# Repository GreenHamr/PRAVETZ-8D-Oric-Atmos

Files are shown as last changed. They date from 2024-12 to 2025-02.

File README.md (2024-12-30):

PRAVETZ-8D Plus Project

An 8-bit home computer using a home TV instead of a monitor. 
Programmatically incompatible with Pravets 82 family computers (due to the different architecture). 
An analogue of Oric Atmos. At first, it only works with a tape recorder (after 1990, floppy drives 
for it also appeared, united in one housing with the controller[3]. 
It has improved sound capabilities, through a Yamaha microcircuit. It is widely used for home use 
and for training The extremely attractive price of the model (about 10 times lower than Pravets 82) 
gives high hopes for this model and not a few students have taken their first steps on Pravets 8D.

That's what happened to me. My first personal computer was a Pravetz-8D (Oric Atmos).

About a year ago I remembered my old childhood friend and wondered if I could make one of these.
Of course, first I called my mother to ask her if my old computer was still lying in a basement in my old house. To my great surprise, I found out that she had put it in a briefcase along with a pack of floppy disks.
A little battered and missing a single key, but - WORKING.
Unfortunately, the floppy disk drive and the controller were not preserved.

<br>
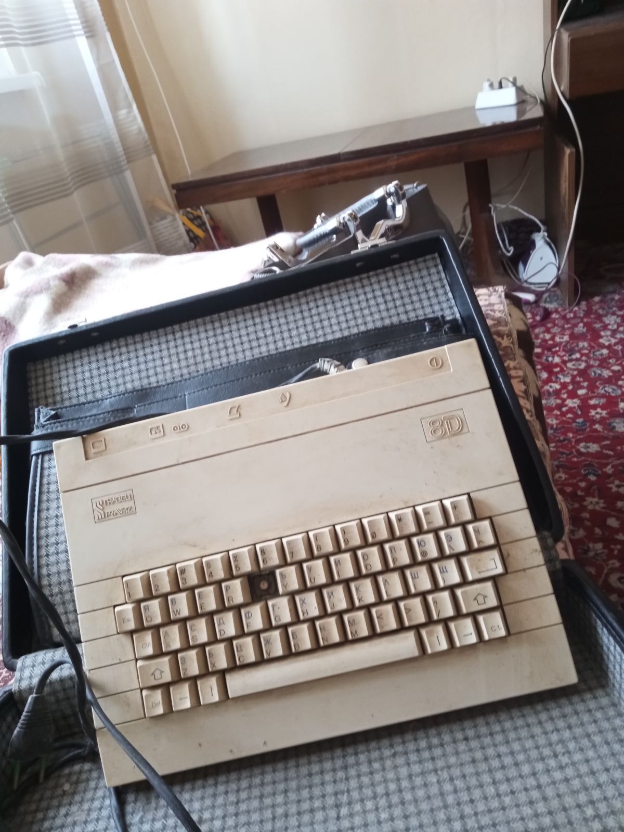
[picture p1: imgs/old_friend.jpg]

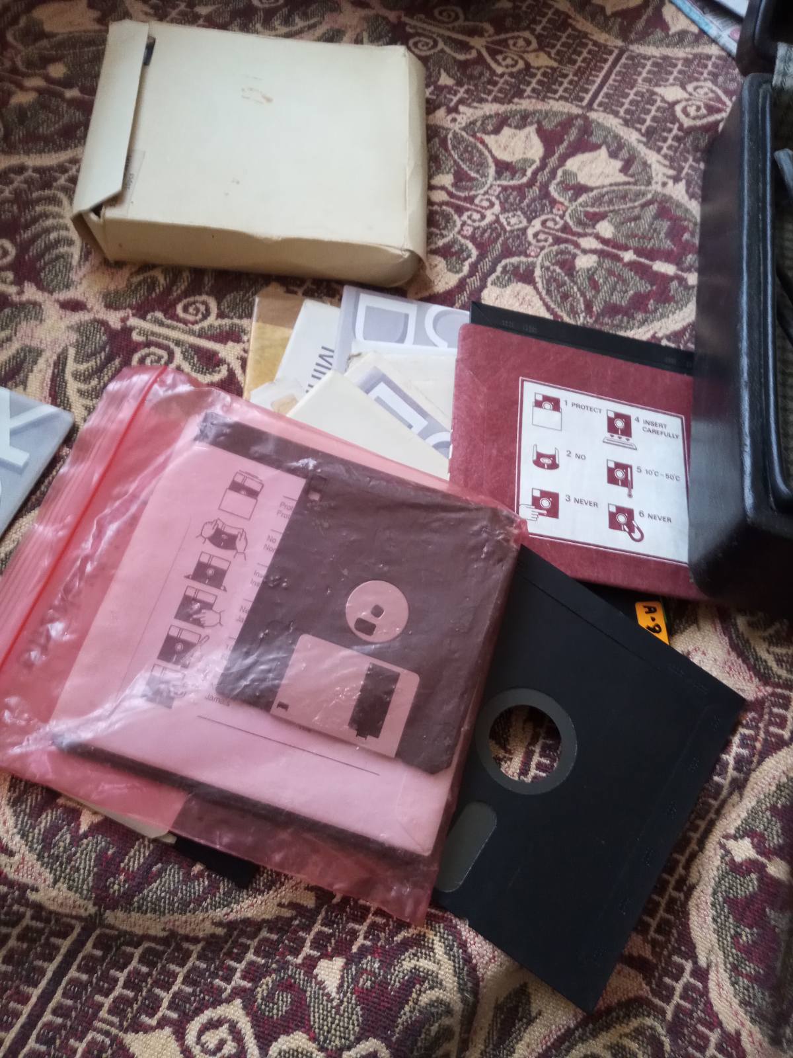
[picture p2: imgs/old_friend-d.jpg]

<br>

So, first I decided to make my own floppy disk controller. Some time ago I had bought one from Boyan Mitov - a very well made board.
I searched the internet but couldn't find a schematic. I bought a kit (a blank board plus PROMs) which I filled up and with a few extras I got it working. But the person I bought this board from said that there were only the gerbers and no schematic.

So I set out to develop such a controller myself.
And since we are already in the 21st century, I decided to use a Raspberry Pi (RP2040) microcontroller.

After several unsuccessful attempts and a lot of digging on the Internet , I got to assemble a floppy disk controller based on the RP2040 plus the schematic solution of the APPLE II for a floppy disk controller. (<a href = "https://en.wikipedia.org/wiki/Steve_Wozniak">WOZ</a> STATE MACHINE) - a very good solution.

During the development, I also had the idea of making a dynamic ROM. For this purpose, I used another RP 2040 which simulates the operation of a standard 27C128 ROM, but it has the ability to change four pages from one bank on the fly. I set eight banks that can be selected when the system is started.

I put all this together on one board. I also made a keyboard for it and the result is this:
<br>
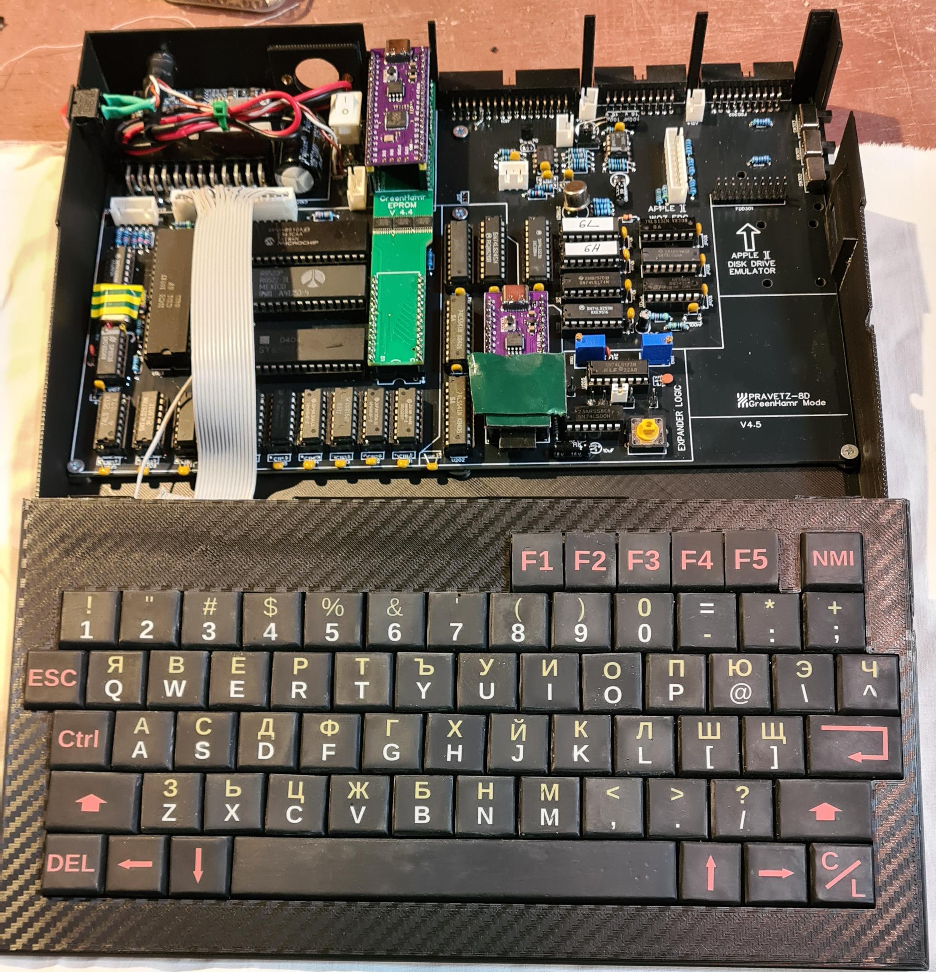
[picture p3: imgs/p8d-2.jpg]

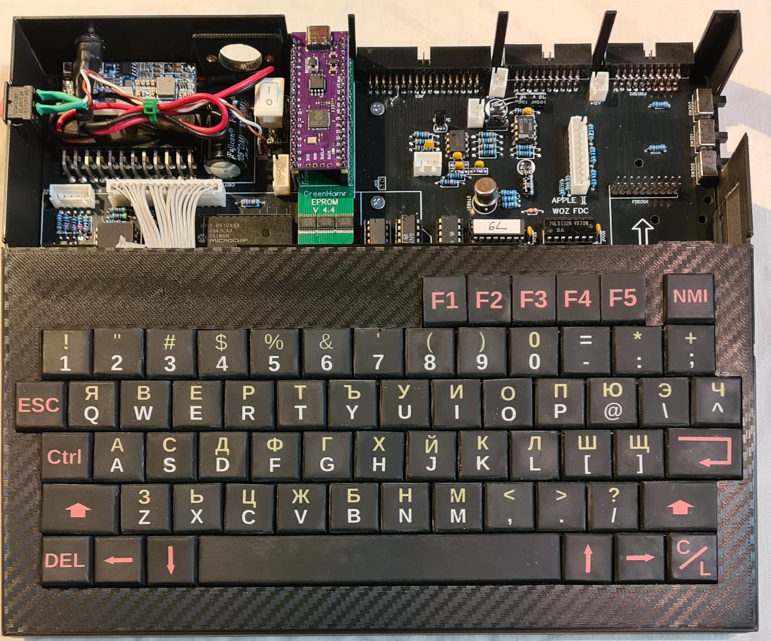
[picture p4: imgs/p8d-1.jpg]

<br>

I designed a box. It also underwent a lot of changes along with the changes in the board.

I encountered a problem with the monitor.
Pravets-8d (orits) has a monitor output (RGBS) which is however at 15kHz. I was unable to find such an LCD monitor. I found a converter board on the internet which works quite well, but it is very large and if I want to make this computer with nice shapes this board does not work for me.
So I set about making my own upscaler - another RP2040 which intercepts the video signal generated by the HCS10017 ULA and converts it to a standard LCD.

After I made the upscaler, I mounted everything in the top cover of the machine.

<br>
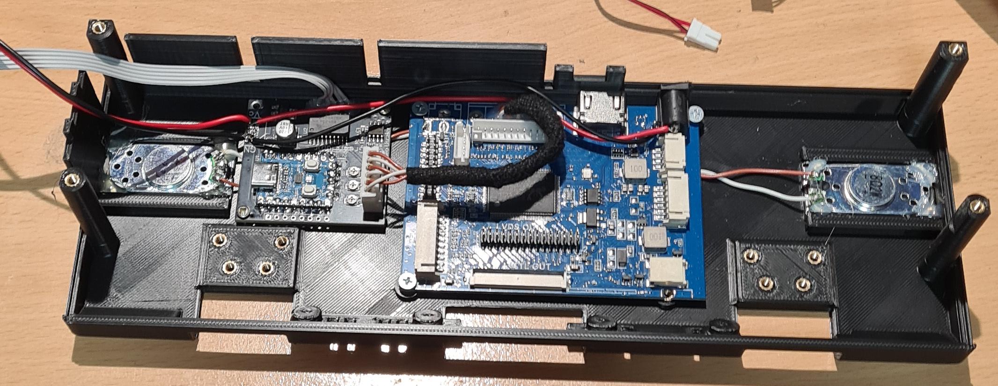
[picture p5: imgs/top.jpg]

<br>

And fully wired : 

<br>
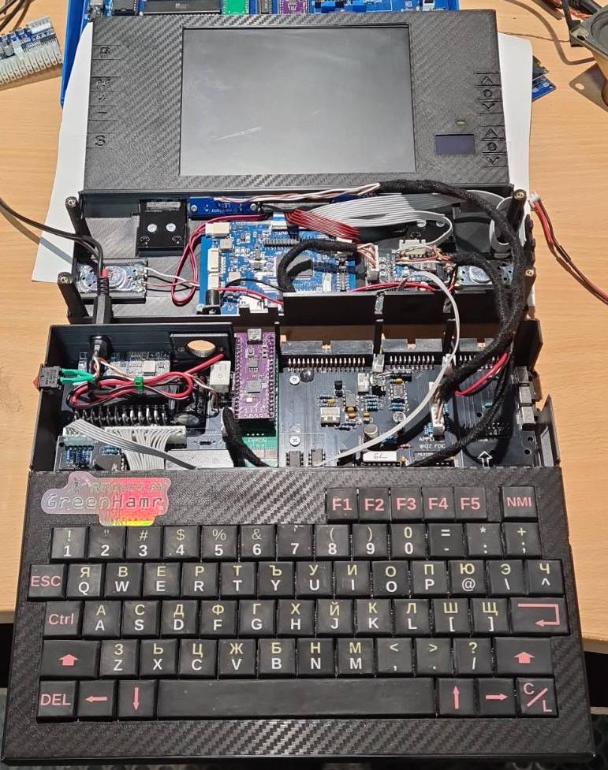
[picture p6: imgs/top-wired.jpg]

<br>

here is a back of dosplay : 

<br>
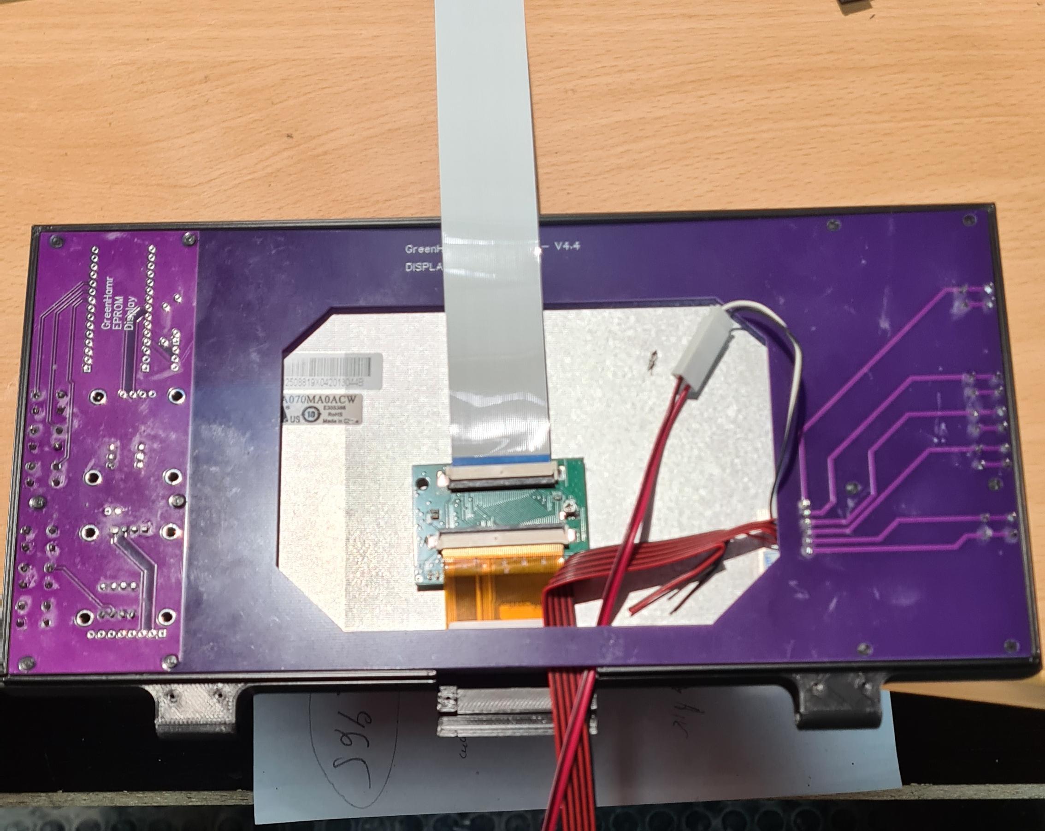
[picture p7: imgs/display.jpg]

<br>

So,
After I did all the wiring, it was finally time to close the whole computer and test it. Everything is OK.

<table border=0>
<tr>
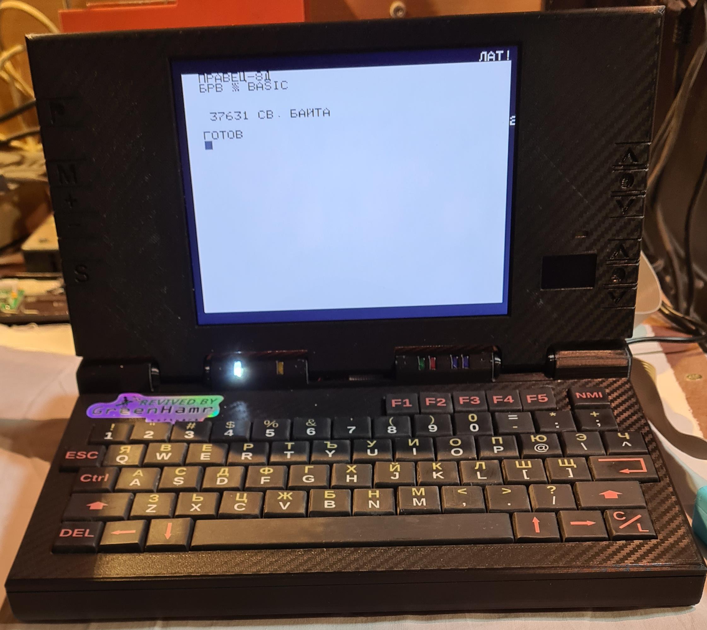
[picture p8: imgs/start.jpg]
<td></td>
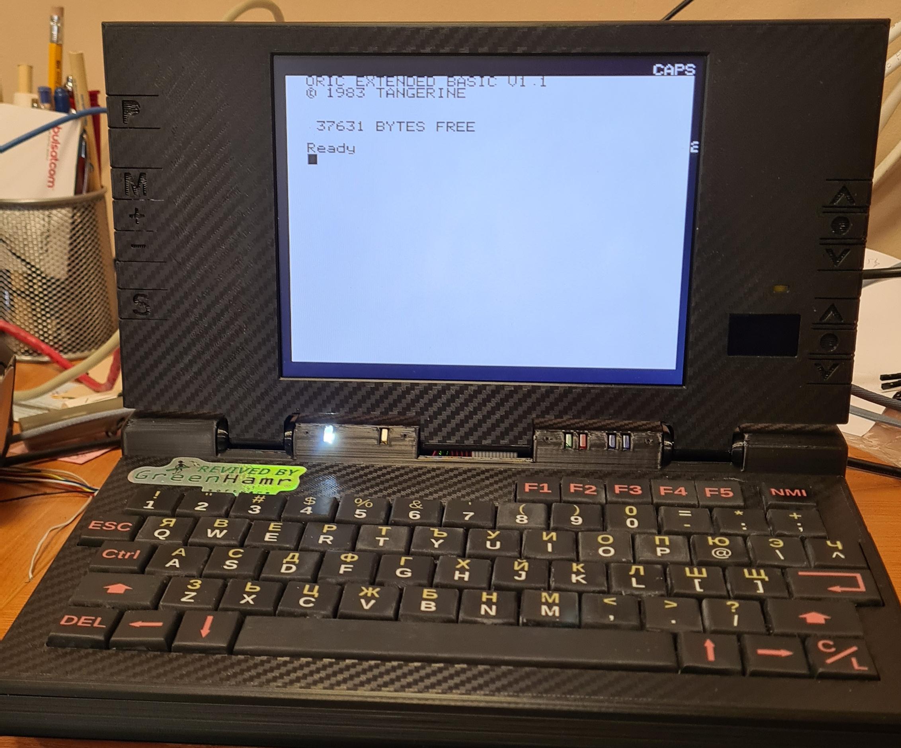
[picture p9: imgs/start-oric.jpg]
<td></td>
</tr>
<tr>
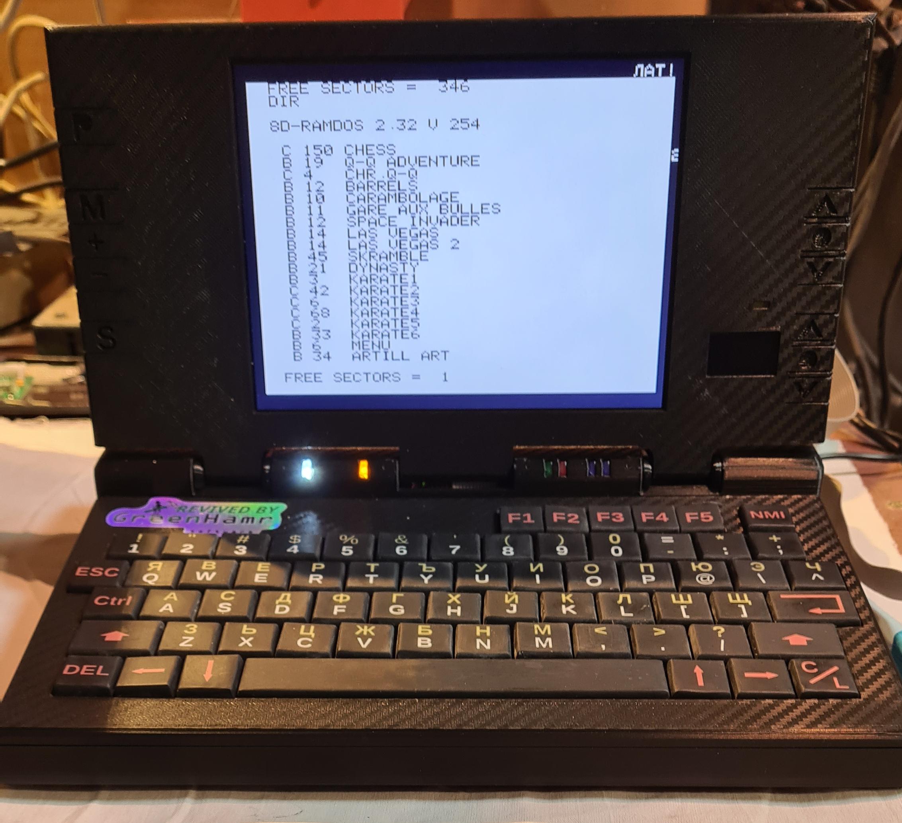
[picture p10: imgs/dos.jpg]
<td></td>
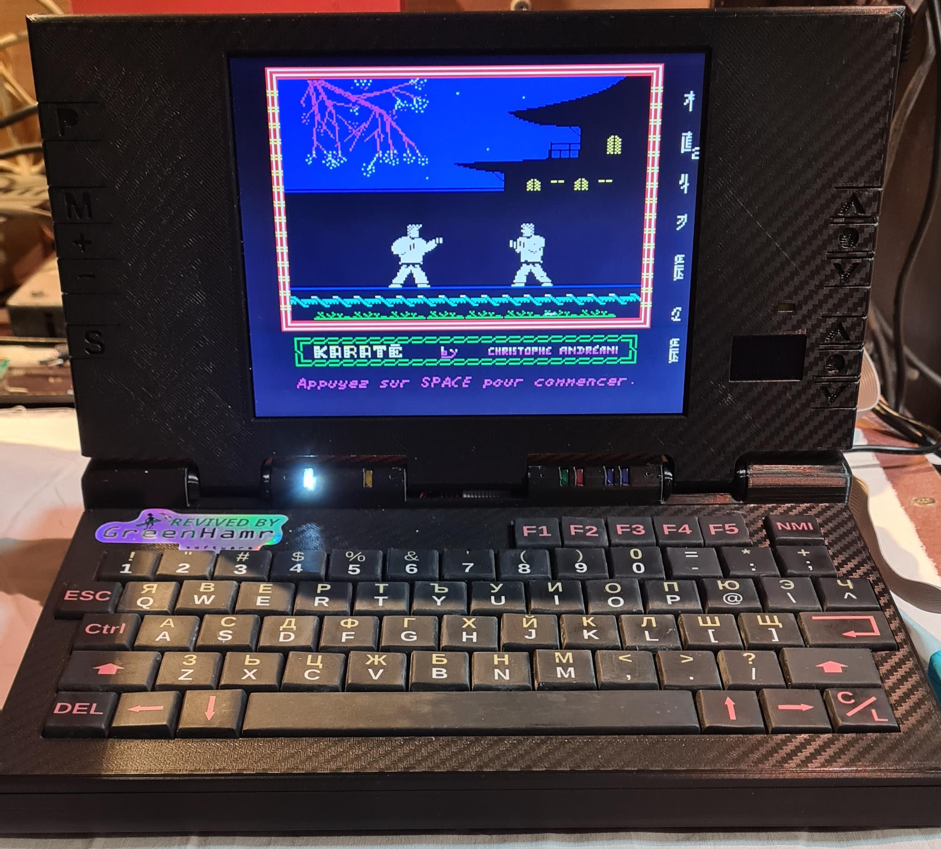
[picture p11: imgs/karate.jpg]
<td></td>
</tr>
</table>

<br>

<font size=+3><b>Let's talk about the project.</b></font>

<br><br>

For design Schematics and PCBs I use <a target="NEW" href=https://easyeda.com/> EasyEDA </a> system. 
And order boards direcly from this CAD to <a target="NEW" href=https://jlcpcb.com/>JLCPCB</a>

You can find this projects here : 
<table>
<tr><td><a target="NEW" href=https://u.easyeda.com/account/user/projects/index/detail?project=c6d01d93ac2549a29140f4bee5cfe490&listType=all> Main LOGIC - AY-3-8910</a></td></tr>
<tr><td><a target="NEW" href=https://u.easyeda.com/account/user/projects/index/detail?project=a509fb325f5442a4b764fb28fe258eaf&listType=all> Keyboard</a></td></tr>
<tr><td><a target="NEW" href=https://u.easyeda.com/account/user/projects/index/detail?project=205ad6d6b13543d9b9c6c1f6ccf78b0d&listType=all> VIDEO upscaler</a></td></tr>
<tr><td><a target="NEW" href=https://u.easyeda.com/account/user/projects/index/detail?project=bce4df32041e4f5abfc7ceaee0b3d13a&listType=all> EPROM - extender</a></td></tr>
<tr><td><a target="NEW" href=https://u.easyeda.com/account/user/projects/index/detail?project=6507ddaba1c34345acee42c7cf9b6195&listType=all> display and monitor buttons</a></td></tr>
<tr><td><a target="NEW" href=https://u.easyeda.com/account/user/projects/index/detail?project=251d1eb9b4c64a02beb64955f6f17d24&listType=all> LEDs</a></td></tr>
</table>

<font size=+3><b>Changes from original schematics</b></font>
<br>

In the original solution of Oric the sound generator AY-3-8912 was used. However, this chip is hard to find and quite expensive (about 30 EURO), so I dug around and found that there is another one from the same series: AY-3-9810 which performs the same functions, is easier to find and is much cheaper. It can be found for about 2 USD.
<br>
To expand the capabilities of this computer, I also replaced the standard 27C128 EPROM with an emulator that allows you to choose which version of the Program BASIC to choose.
<br>

Everything else is based on the original ORIC solution.
<br>

Unfortunately, it is also difficult to find the specialized ULA HCS10017 chip, but it is still available on the market. I found a few on eBay.

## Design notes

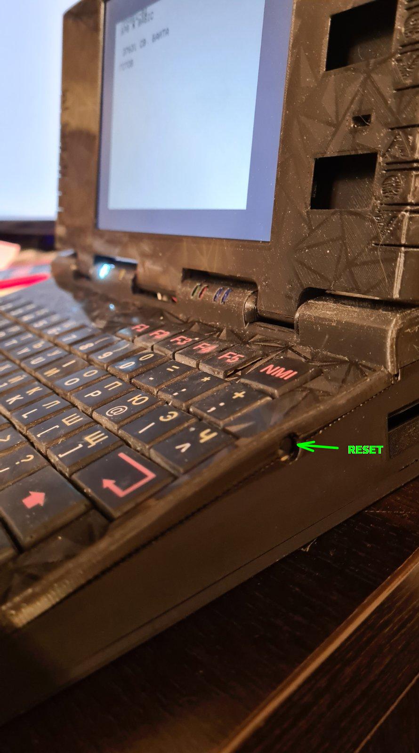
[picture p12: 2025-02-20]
imgs/reset.jpg

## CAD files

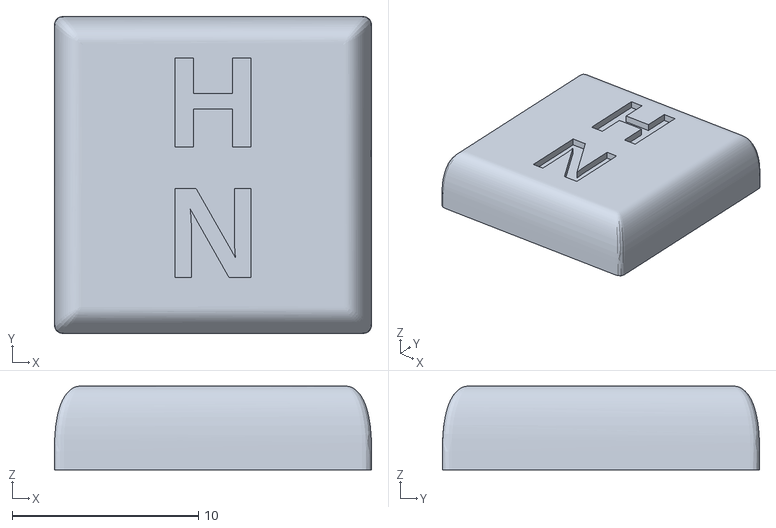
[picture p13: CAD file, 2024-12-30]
STL/KEYBOARD/KEYs/17_17/KEY_N.stl
17.0 x 17.0 x 4.50

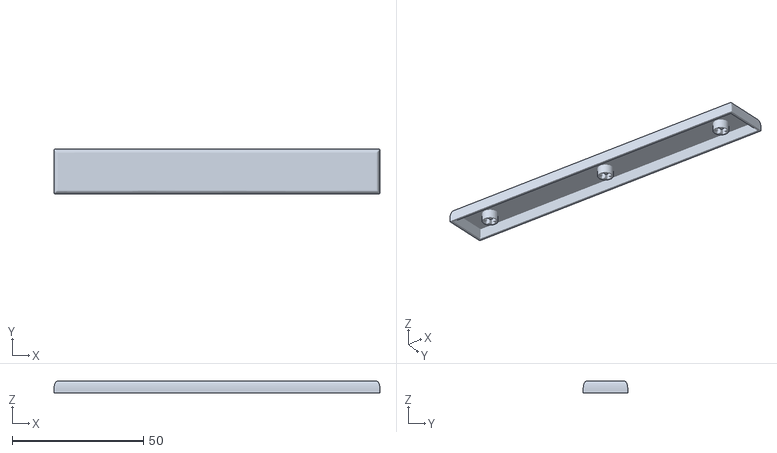
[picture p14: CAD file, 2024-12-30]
STL/KEYBOARD/KEYs/KEY_Space.stl
124.0 x 17.0 x 4.50

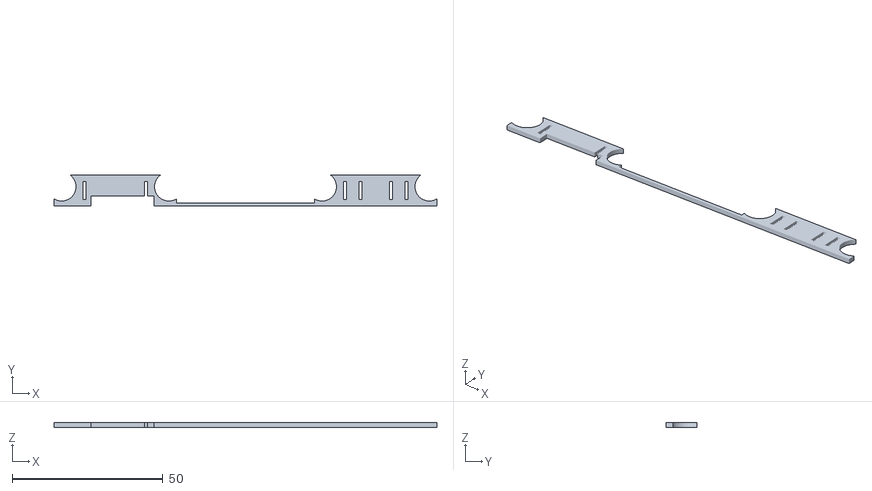
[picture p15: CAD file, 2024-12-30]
STL/KEYBOARD/PRAVETZ-8D-V4.4 - LED-spacer.stl
127.0 x 10.2 x 1.50

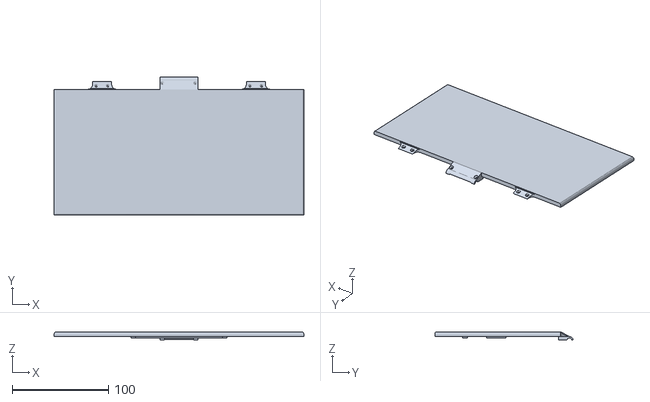
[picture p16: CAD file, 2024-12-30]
STL/PRAVETZ-8D/PRAVETZ-8D - display_back.stl
260.0 x 144.0 x 8.80

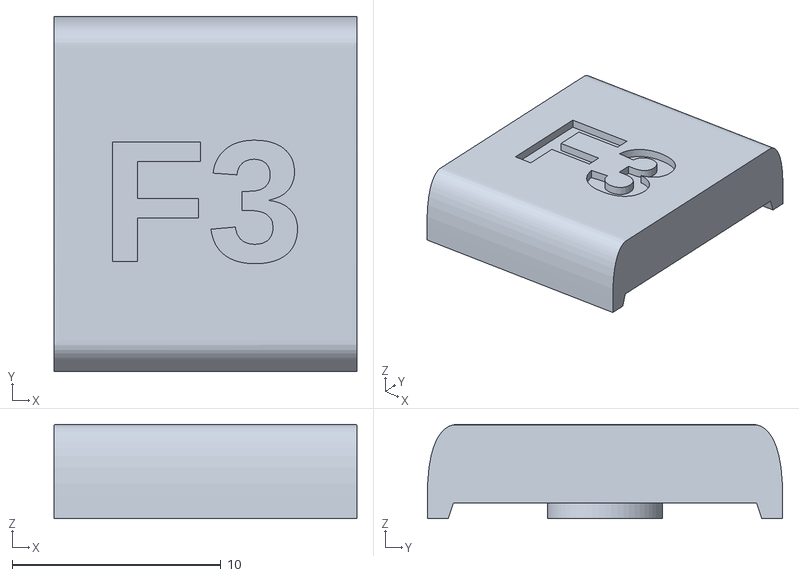
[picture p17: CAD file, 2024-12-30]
STL/KEYBOARD/KEYs/KEY_F3.stl
14.5 x 17.0 x 4.50

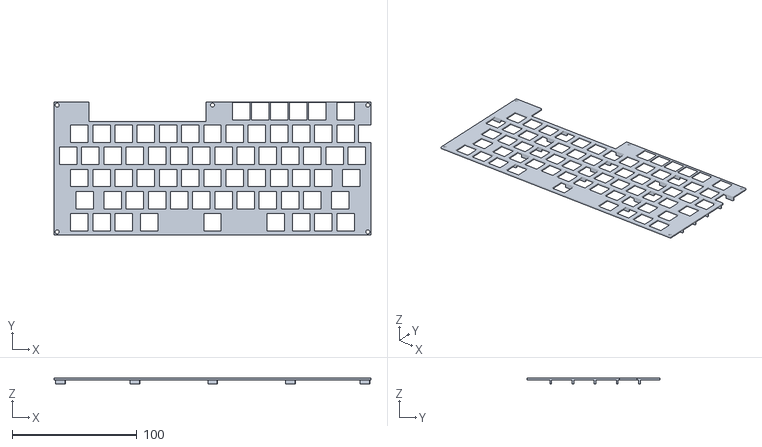
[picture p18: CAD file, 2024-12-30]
STL/KEYBOARD/PRAVETZ-8D-V4.4 - keyboard-mask.stl
254.0 x 106.7 x 5.00

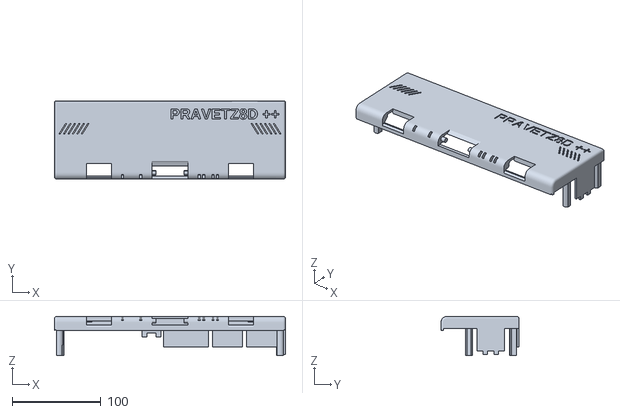
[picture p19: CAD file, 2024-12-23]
STL/PRAVETZ-8D/PRAVETZ-8D - top.stl
260.0 x 88.0 x 44.3

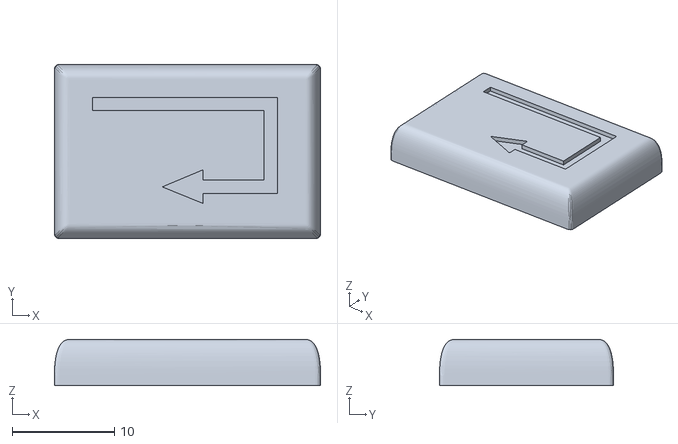
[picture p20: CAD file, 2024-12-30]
STL/KEYBOARD/KEYs/KEY_ENTER.stl
26.0 x 17.0 x 4.50

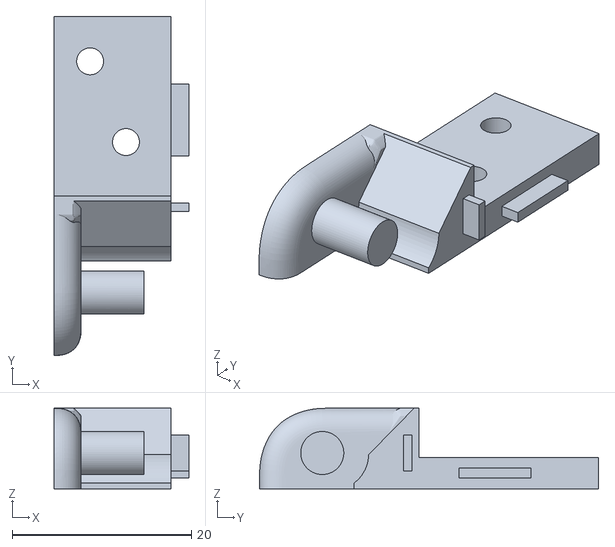
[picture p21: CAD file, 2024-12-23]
STL/PRAVETZ-8D/PRAVETZ-8D - hinge_left.stl
15.0 x 37.8 x 9.00

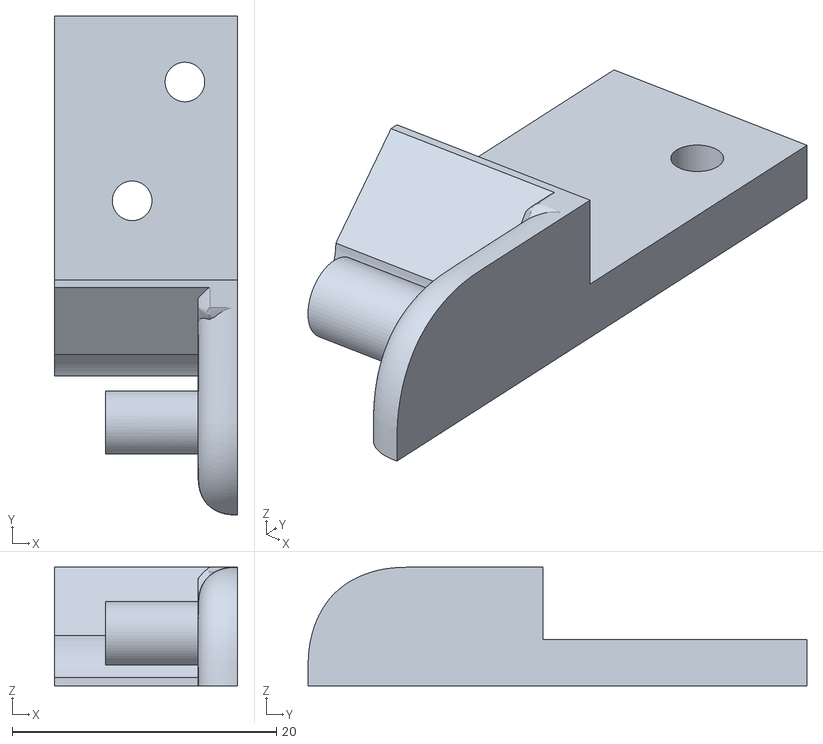
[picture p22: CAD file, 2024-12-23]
STL/PRAVETZ-8D/PRAVETZ-8D - hinge_right.stl
13.9 x 37.8 x 9.00

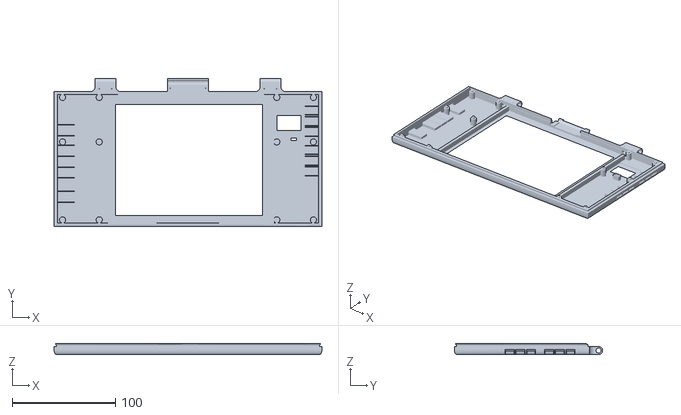
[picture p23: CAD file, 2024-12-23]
STL/PRAVETZ-8D/PRAVETZ-8D - display_front.stl
260.0 x 144.0 x 11.0

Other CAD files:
STL/KEYBOARD/KEYs/17_17/KEY_P.stl
STL/KEYBOARD/KEYs/17_17/KEY_Arrow_left.stl
STL/KEYBOARD/KEYs/17_17/KEY_X.stl
STL/KEYBOARD/KEYs/KEY_F5.stl
STL/KEYBOARD/KEYs/17_17/KEY_LSlash.stl
STL/KEYBOARD/KEYs/KEY_SHIFT_LEFT.stl
STL/KEYBOARD/KEYs/17_17/KEY_T.stl
STL/KEYBOARD/KEYs/17_17/KEY_-.stl
STL/KEYBOARD/KEYs/17_17/KEY_0.stl
STL/KEYBOARD/KEYs/17_17/KEY_1.stl
STL/KEYBOARD/KEYs/17_17/KEY_2.stl
STL/KEYBOARD/KEYs/17_17/KEY_3.stl
STL/KEYBOARD/KEYs/17_17/KEY_4.stl
STL/KEYBOARD/KEYs/17_17/KEY_5.stl
STL/KEYBOARD/KEYs/17_17/KEY_6.stl
STL/KEYBOARD/KEYs/17_17/KEY_7.stl
STL/KEYBOARD/KEYs/17_17/KEY_8.stl
STL/KEYBOARD/KEYs/17_17/KEY_9.stl
STL/KEYBOARD/KEYs/17_17/KEY_@.stl
STL/KEYBOARD/KEYs/17_17/KEY_A.stl
STL/KEYBOARD/KEYs/17_17/KEY_Arrow_down.stl
STL/KEYBOARD/KEYs/17_17/KEY_Arrow_right.stl
STL/KEYBOARD/KEYs/17_17/KEY_Arrow_up.stl
STL/KEYBOARD/KEYs/17_17/KEY_B.stl
STL/KEYBOARD/KEYs/17_17/KEY_C.stl
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

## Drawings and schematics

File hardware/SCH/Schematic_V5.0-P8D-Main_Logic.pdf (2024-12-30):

## HM4864P

## HM4864P

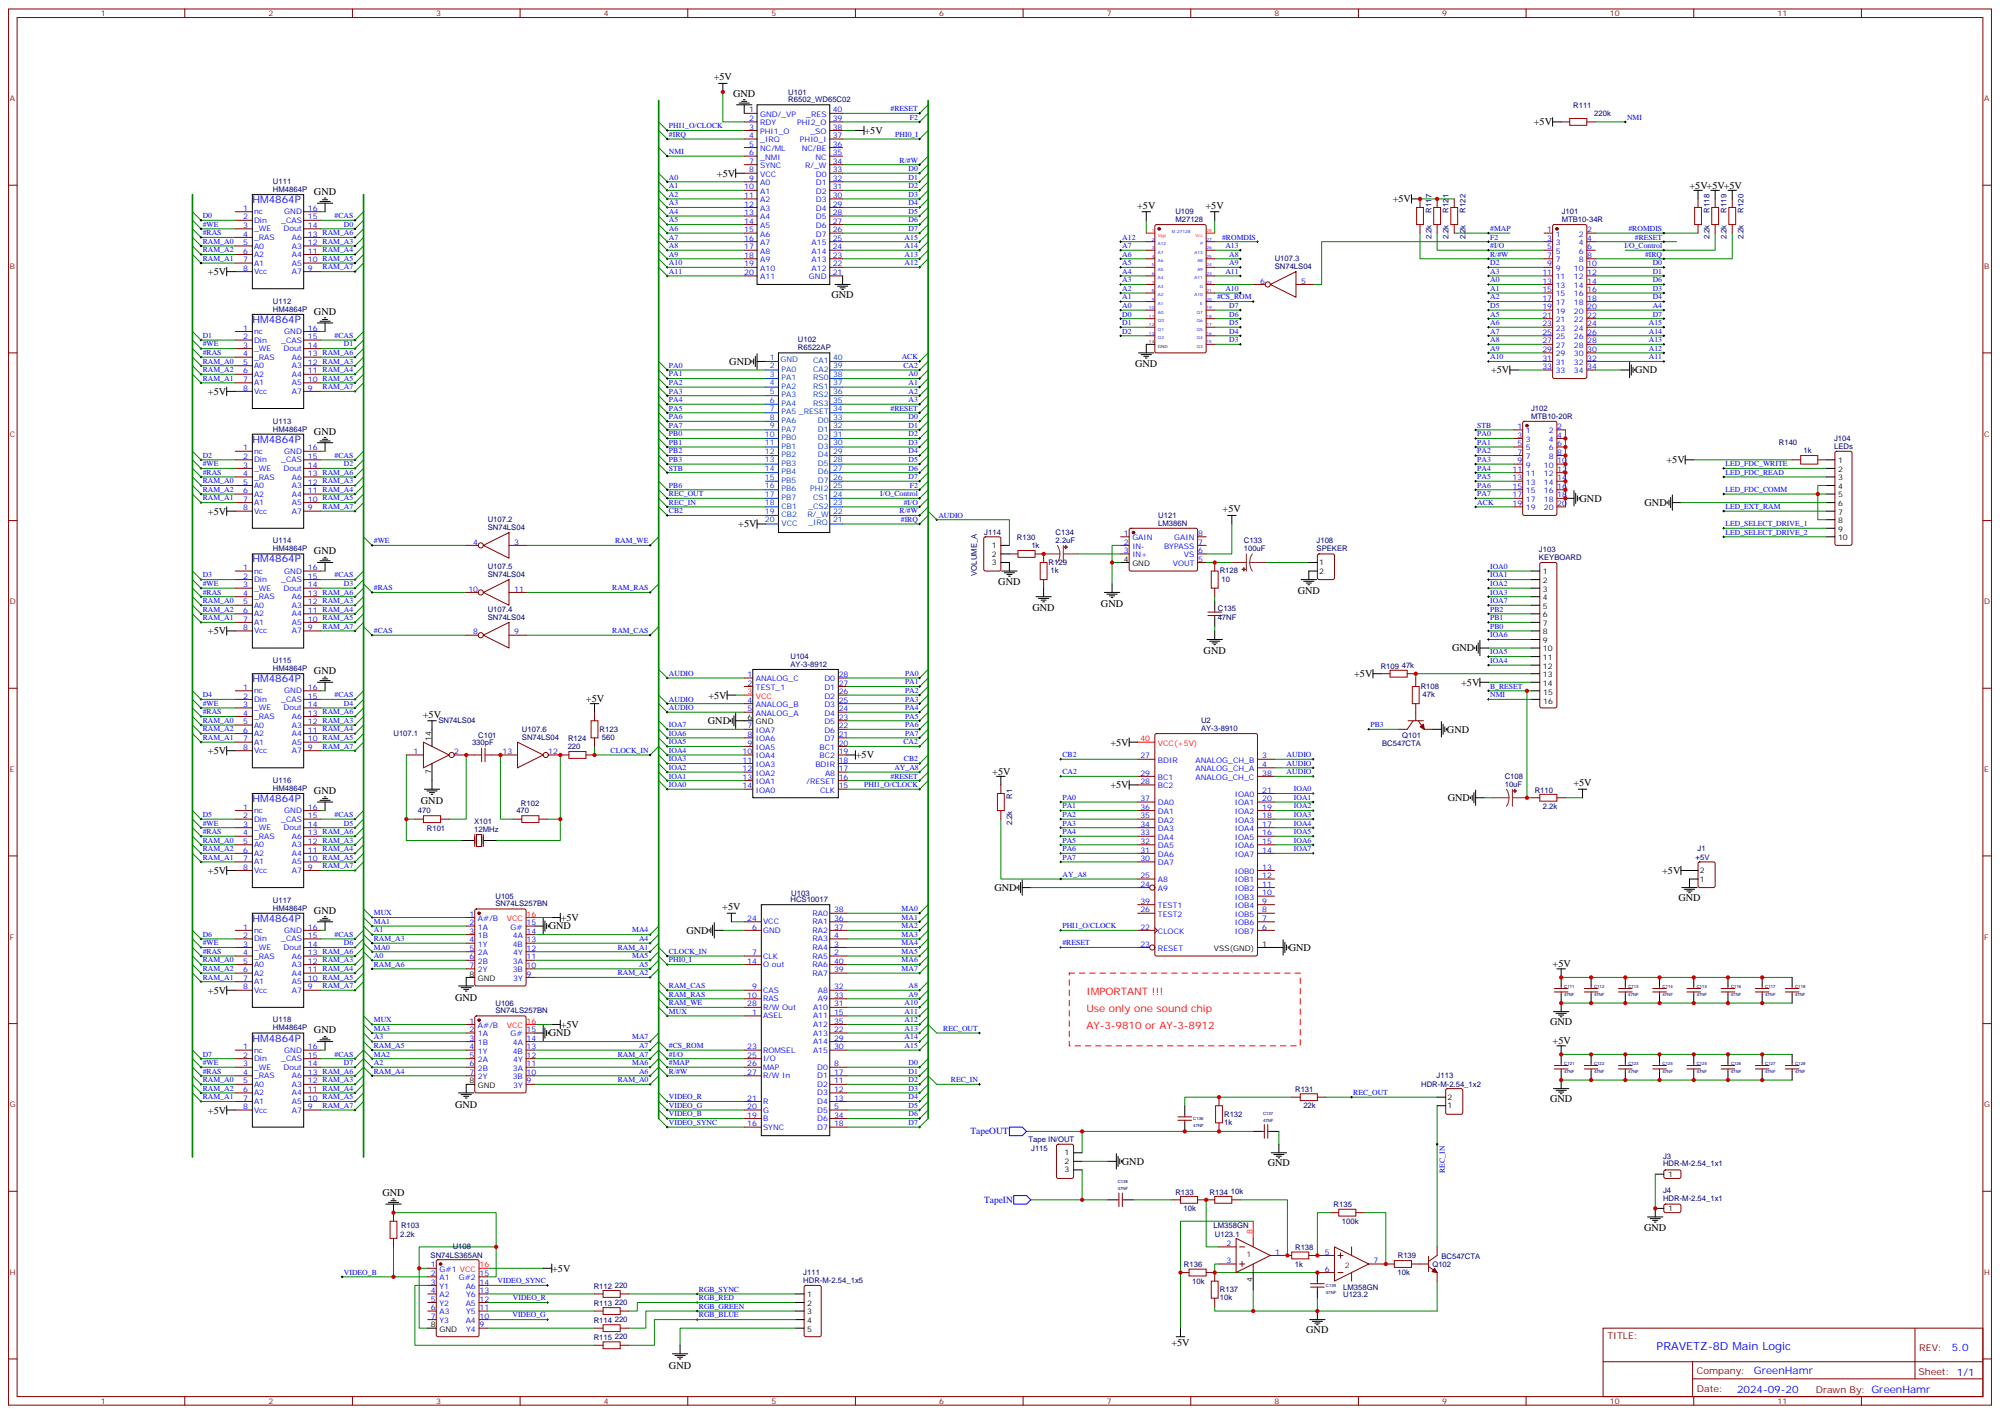
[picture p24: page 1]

IMPORTANT !!!
Use only one sound chip

Y7 | 11 Y6 | 12 Y5 | 13 Y4 | 14 Y3 | 15 Y2 | 16 Y1 | 17 Y0 | 18

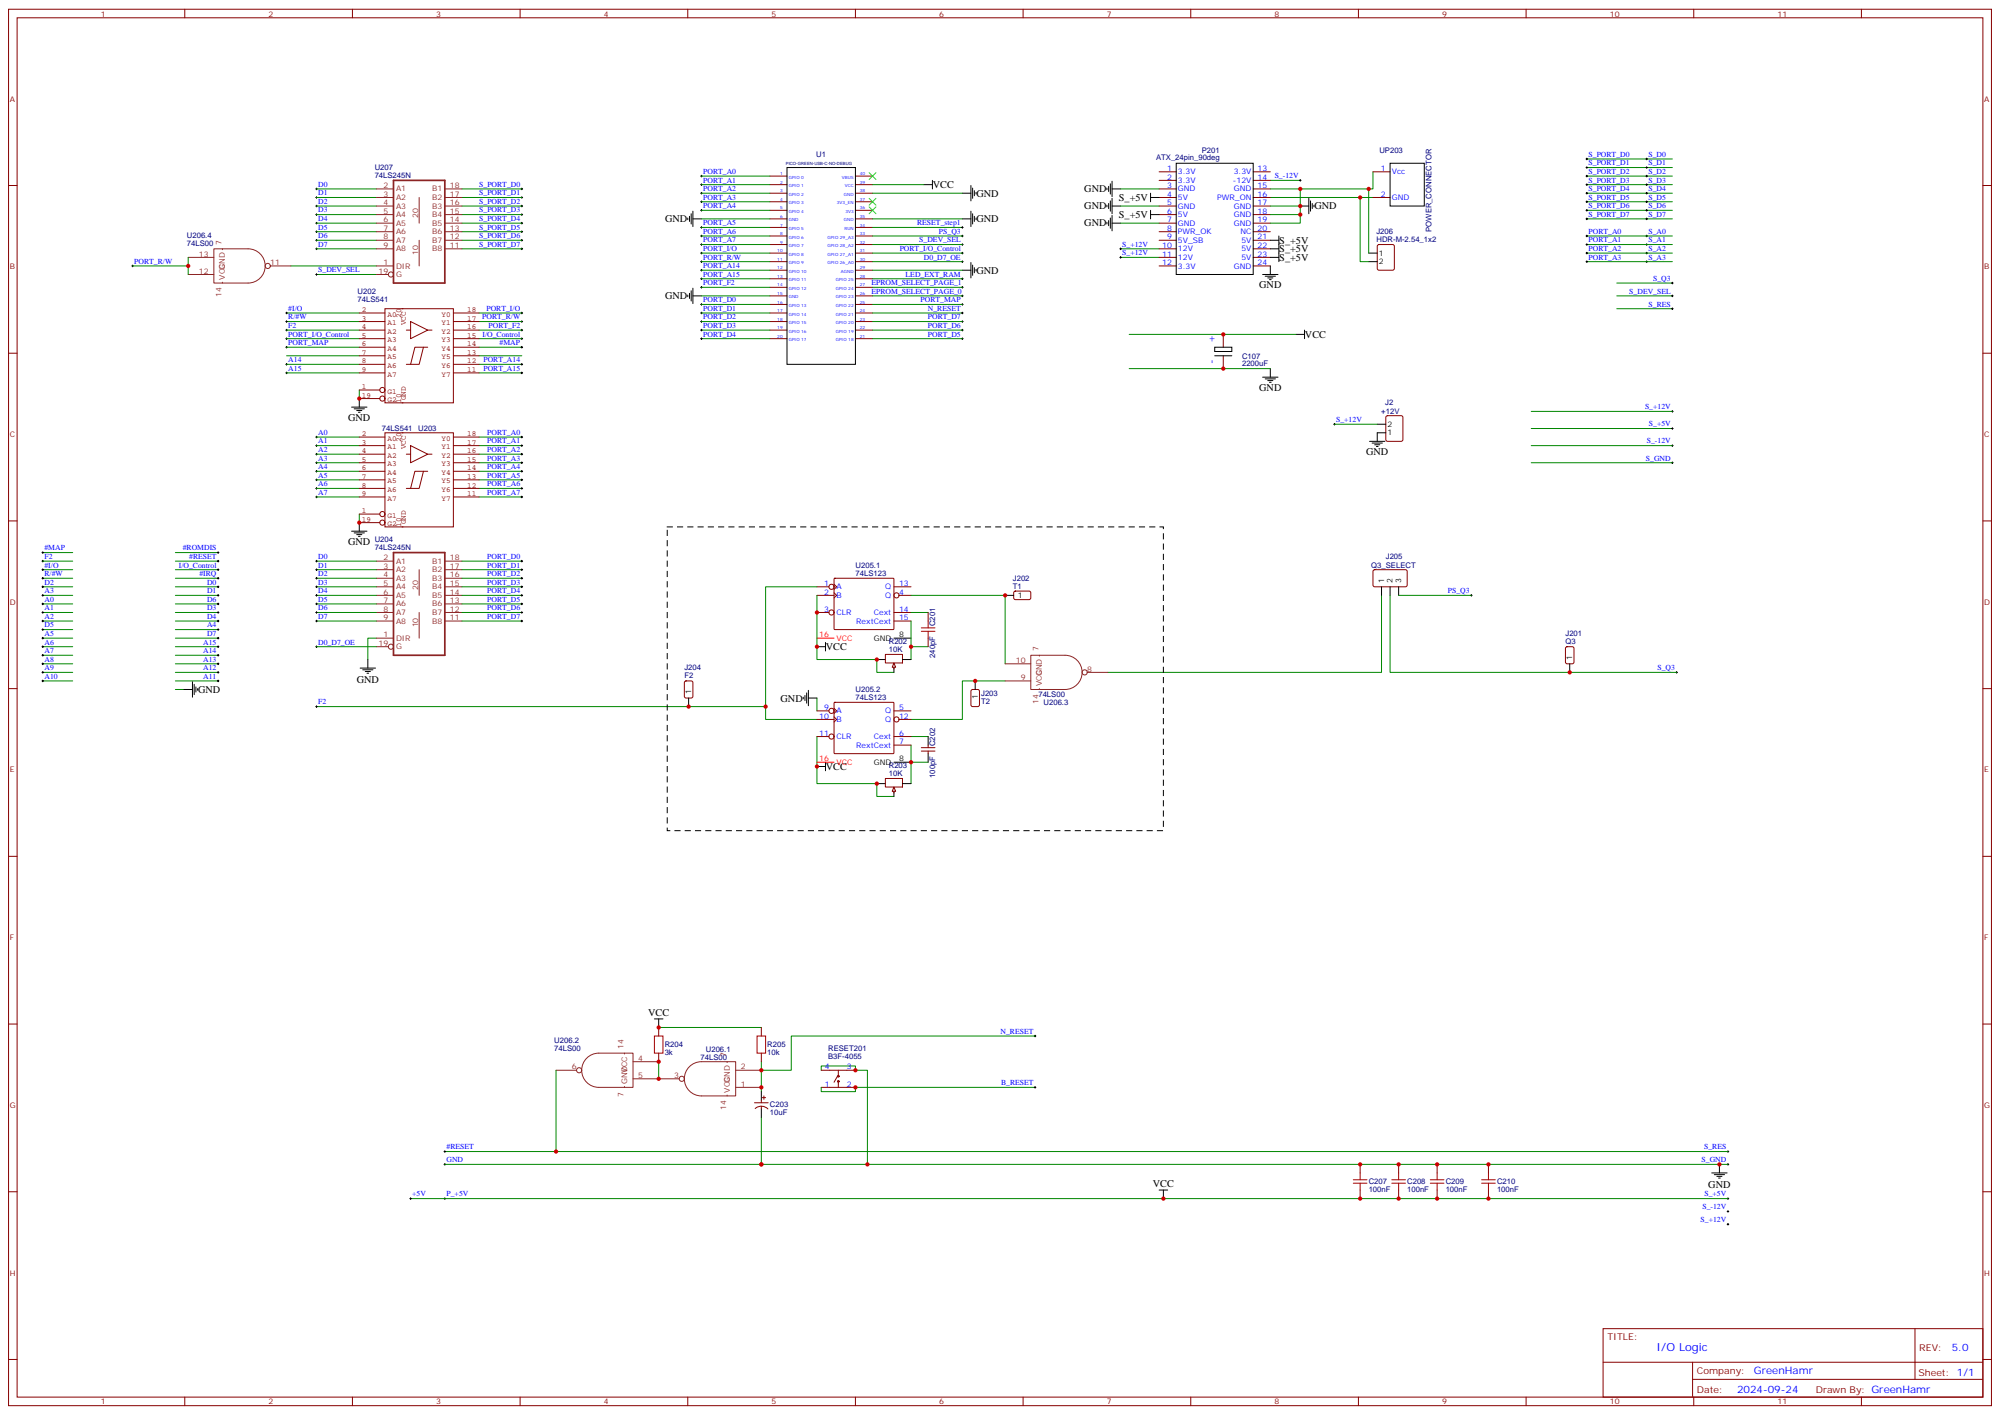
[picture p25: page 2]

PICO-GREEN-USB-C-NO-DEBUG

# 74LS323 GND 10 VCC 20

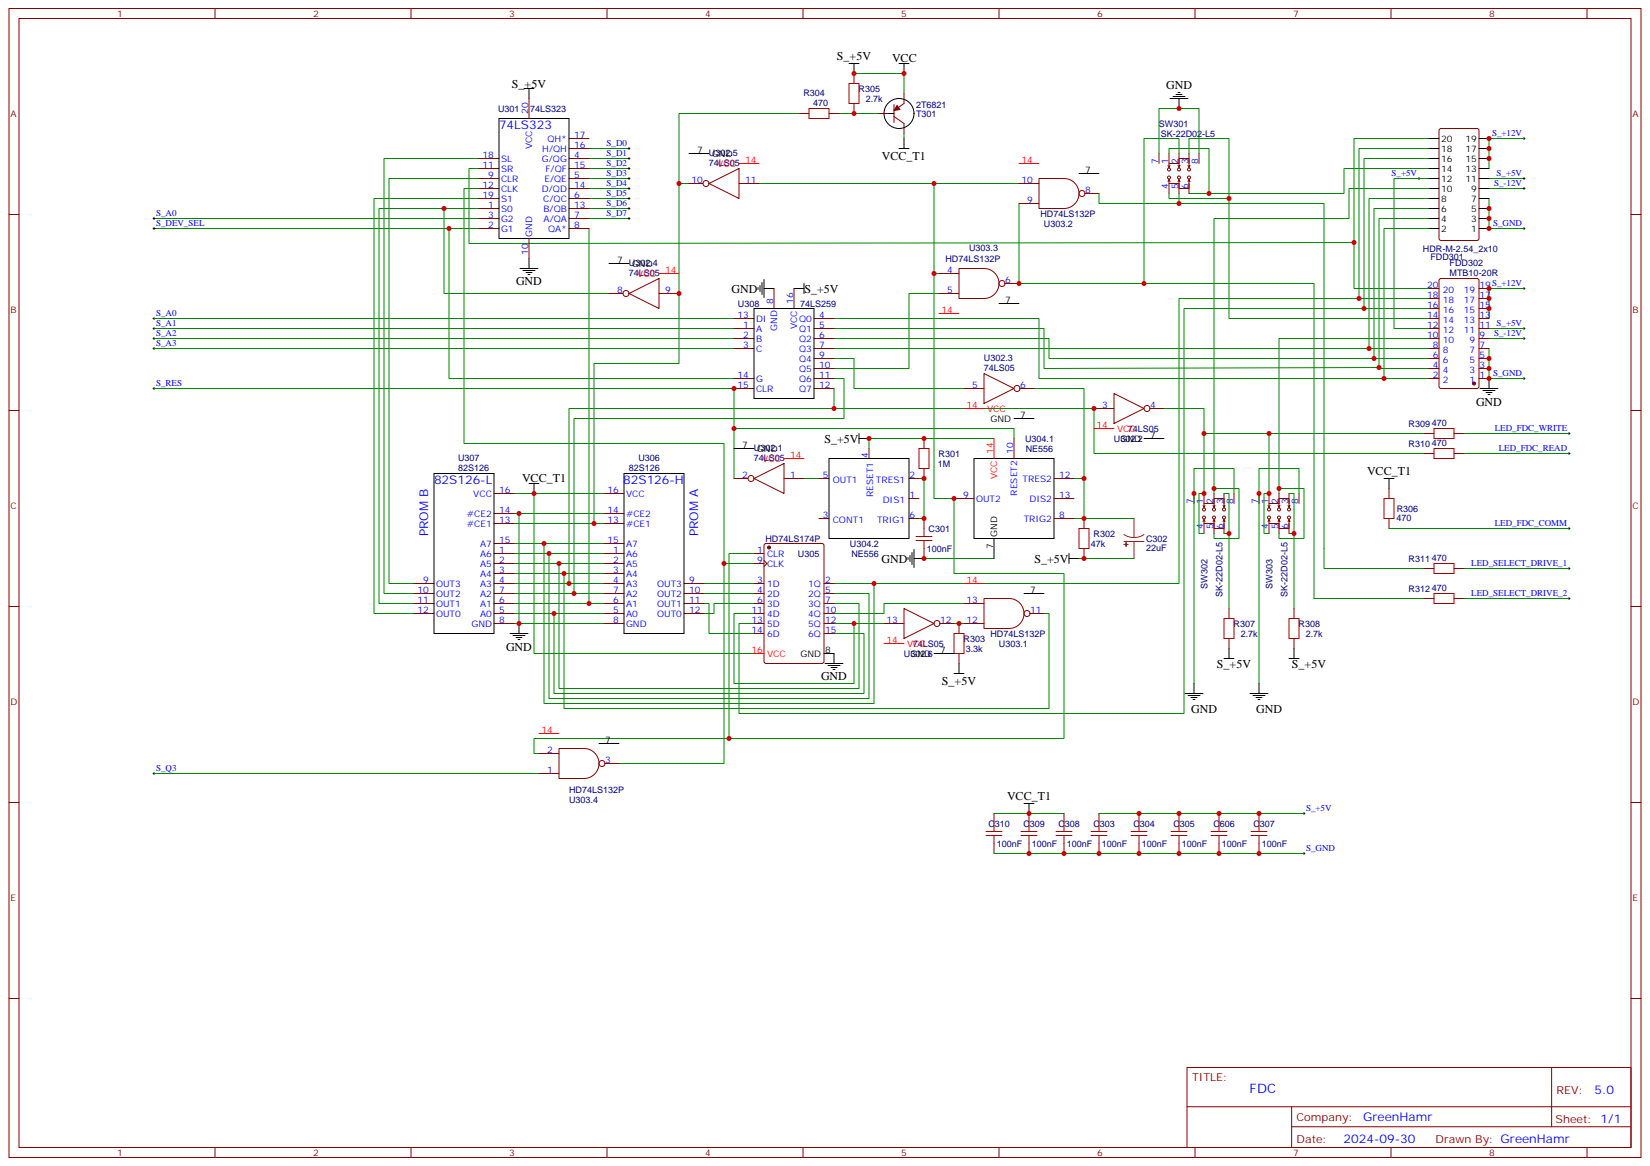
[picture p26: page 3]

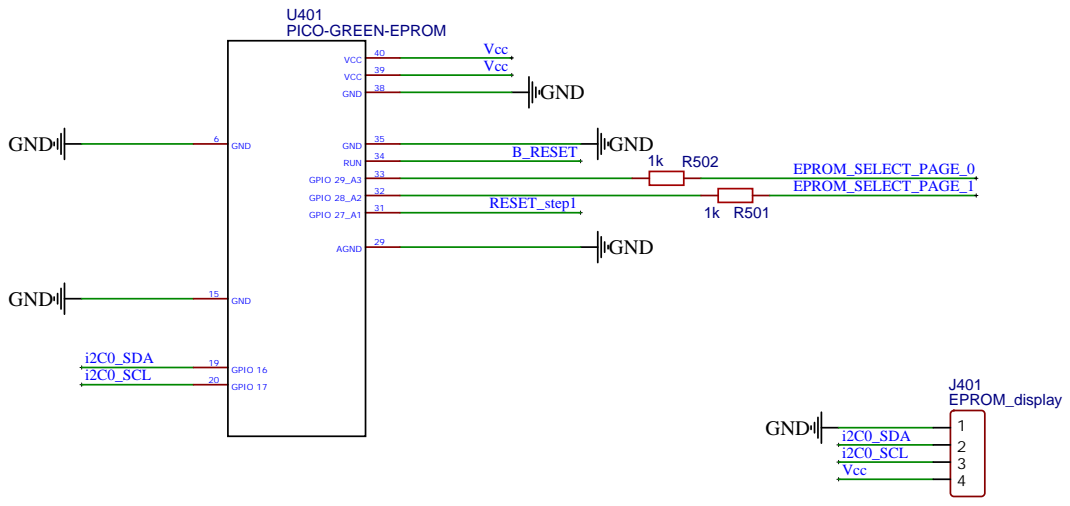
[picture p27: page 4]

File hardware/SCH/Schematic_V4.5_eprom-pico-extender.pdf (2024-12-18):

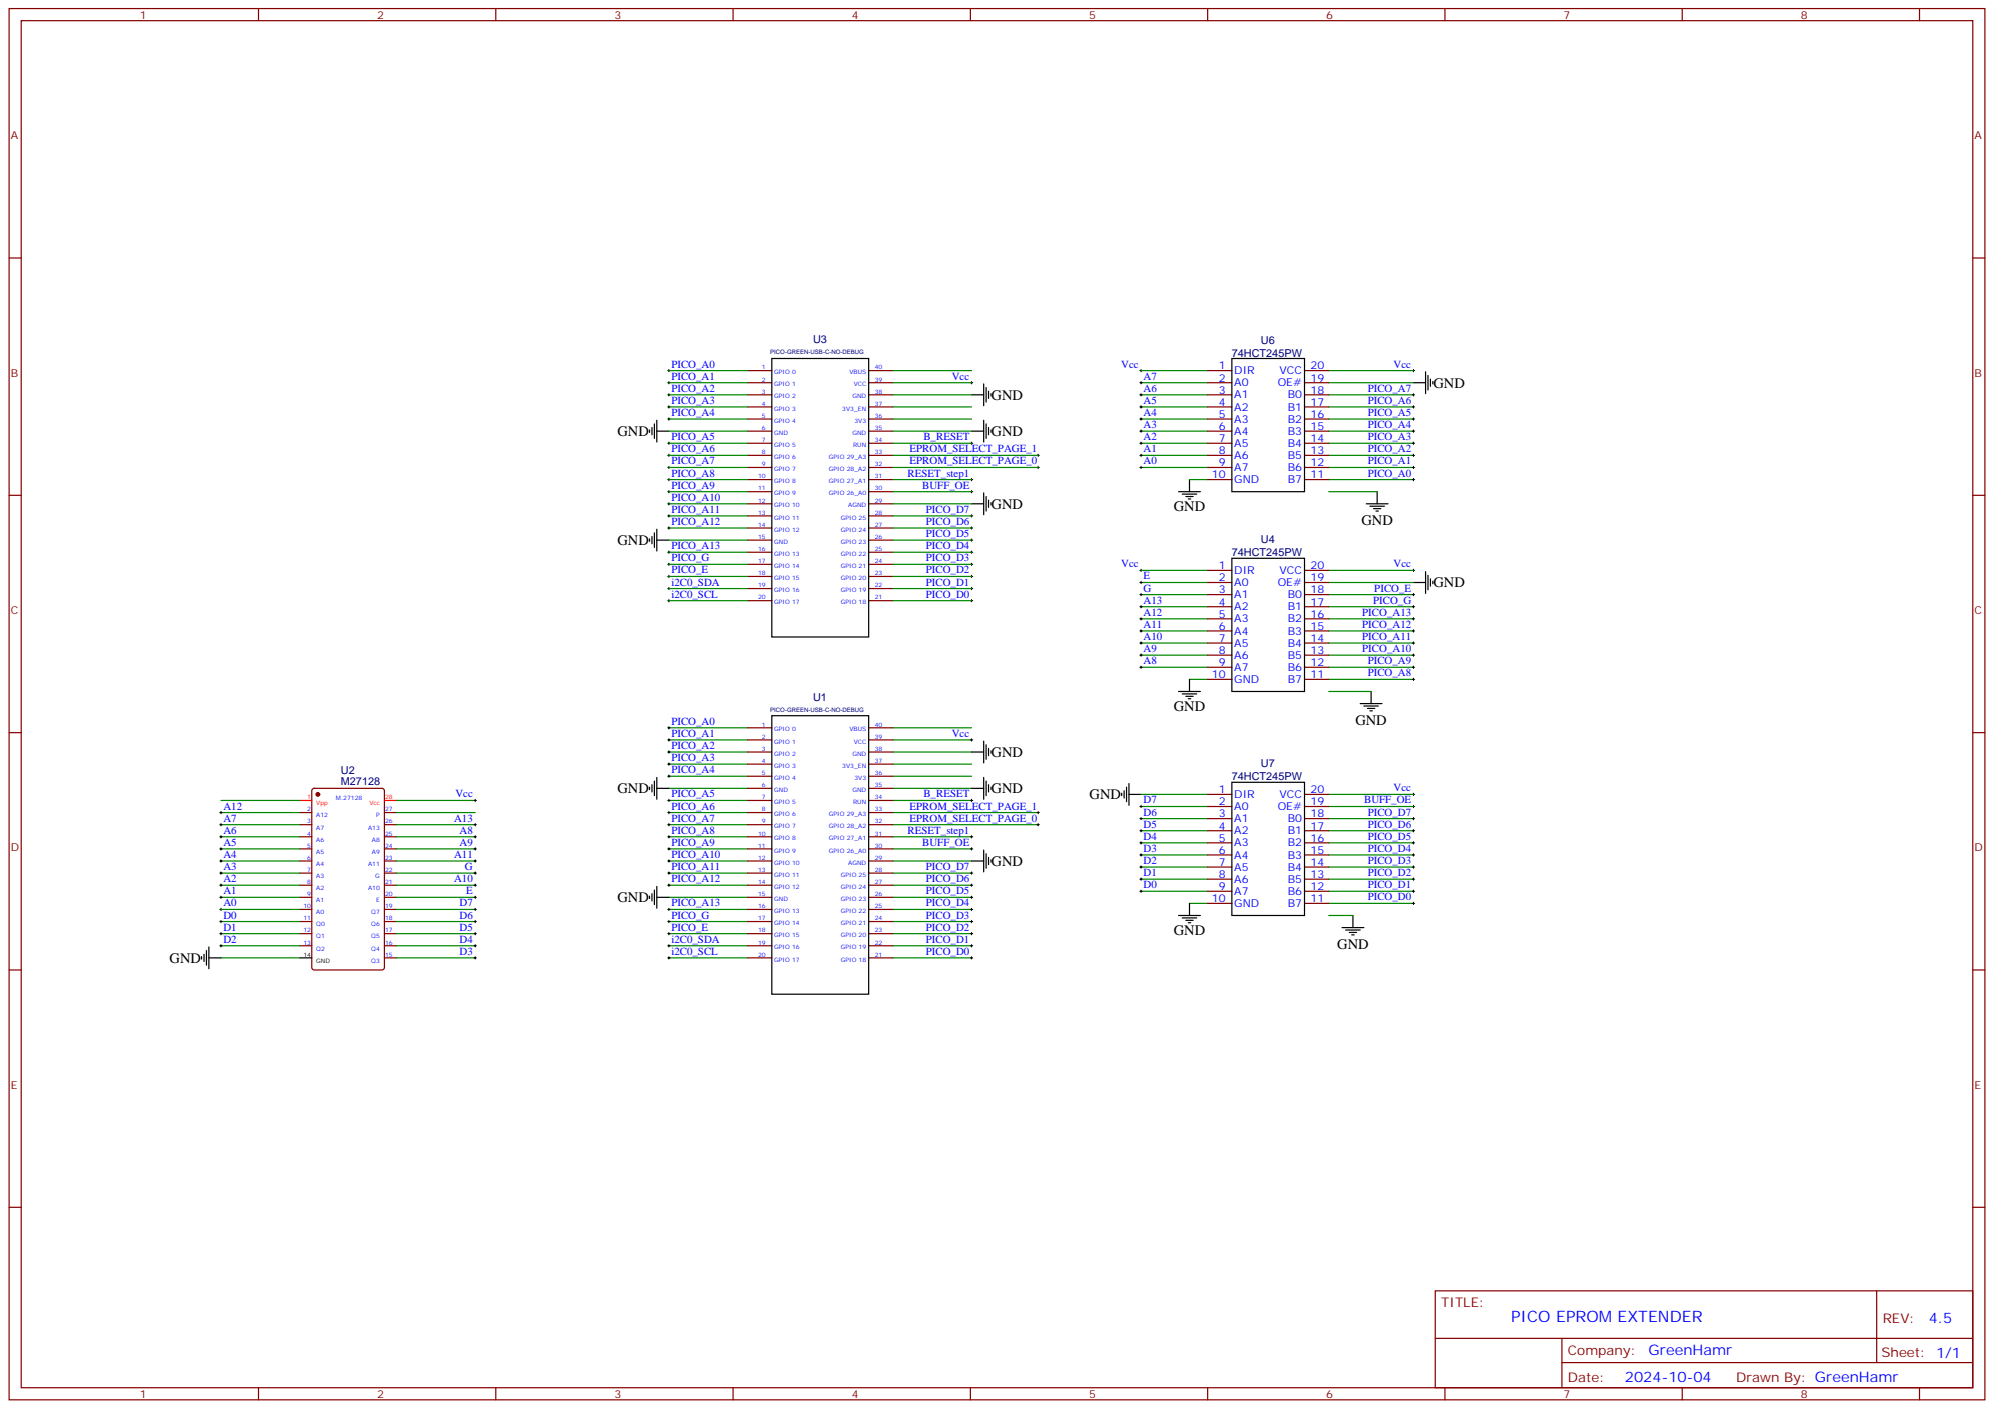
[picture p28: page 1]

PICO-GREEN-USB-C-NO-DEBUG

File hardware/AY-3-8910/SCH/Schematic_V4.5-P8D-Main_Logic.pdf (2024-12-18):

## HM4864P

## HM4864P

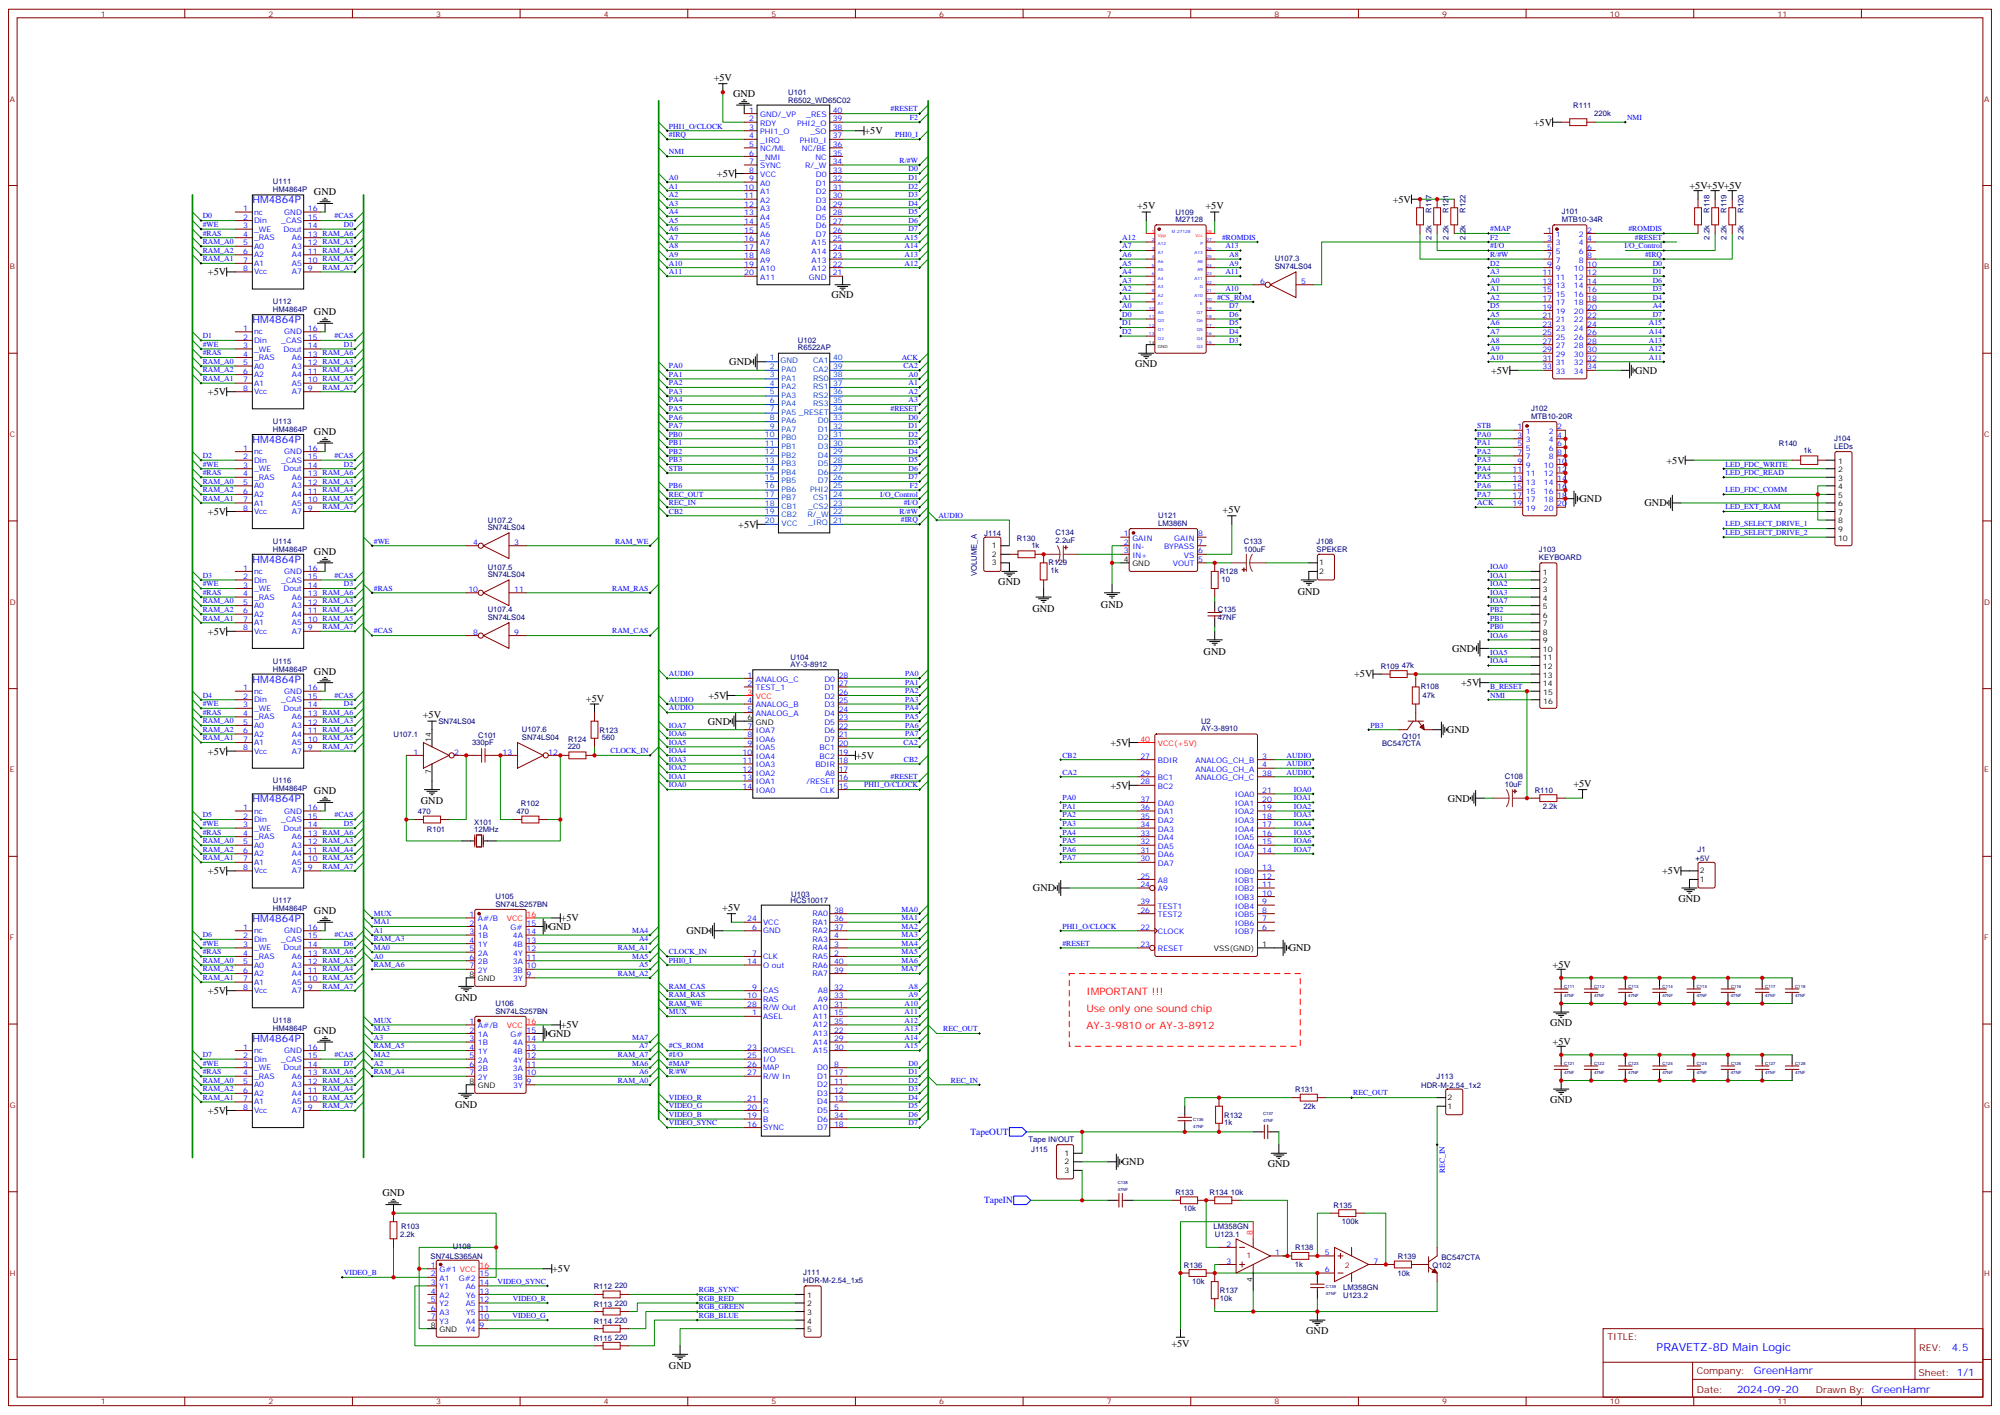
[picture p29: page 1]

IMPORTANT !!!
Use only one sound chip

Y7 | 11 Y6 | 12 Y5 | 13 Y4 | 14 Y3 | 15 Y2 | 16 Y1 | 17 Y0 | 18

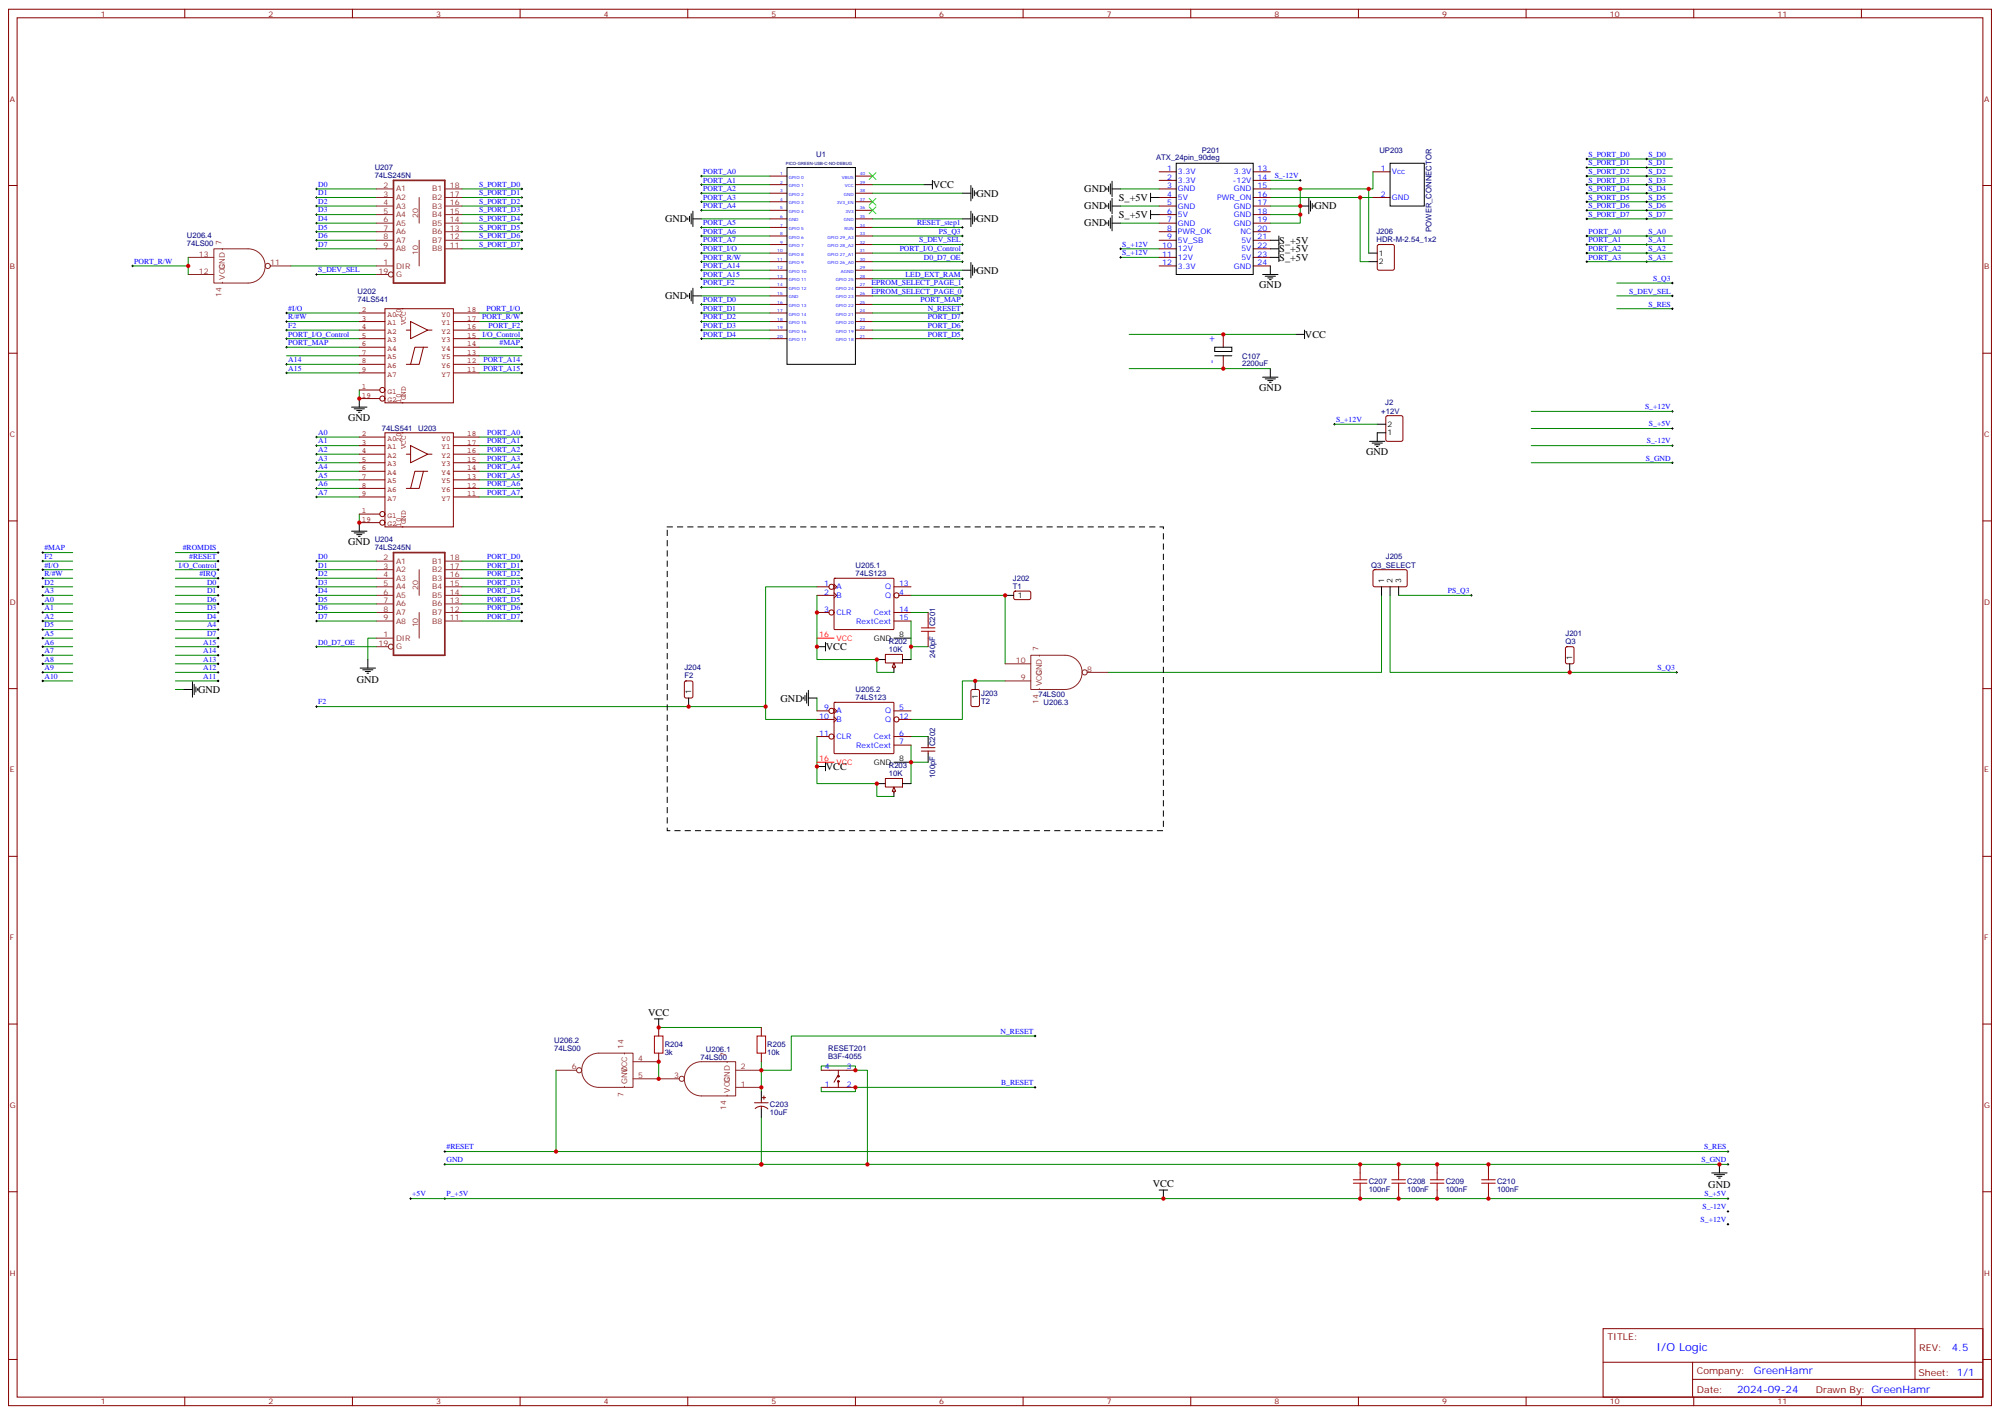
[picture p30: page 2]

PICO-GREEN-USB-C-NO-DEBUG

# 74LS323 GND 10 VCC 20

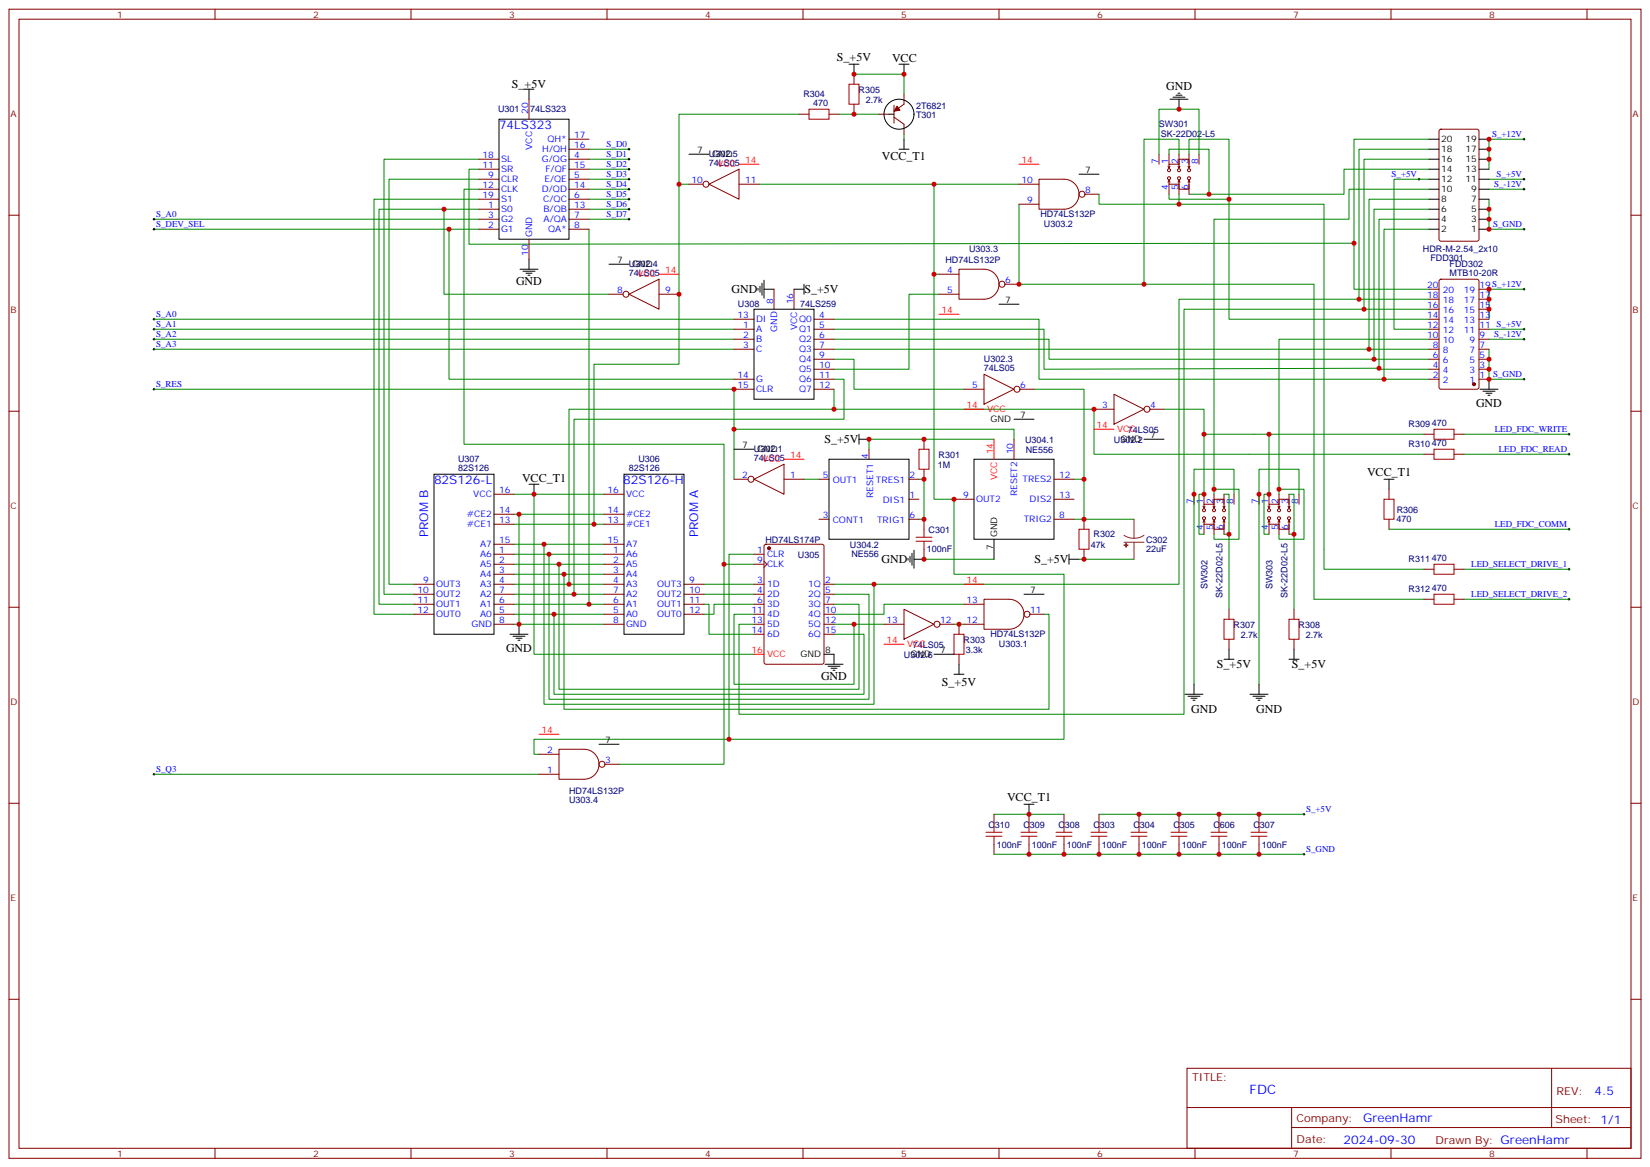
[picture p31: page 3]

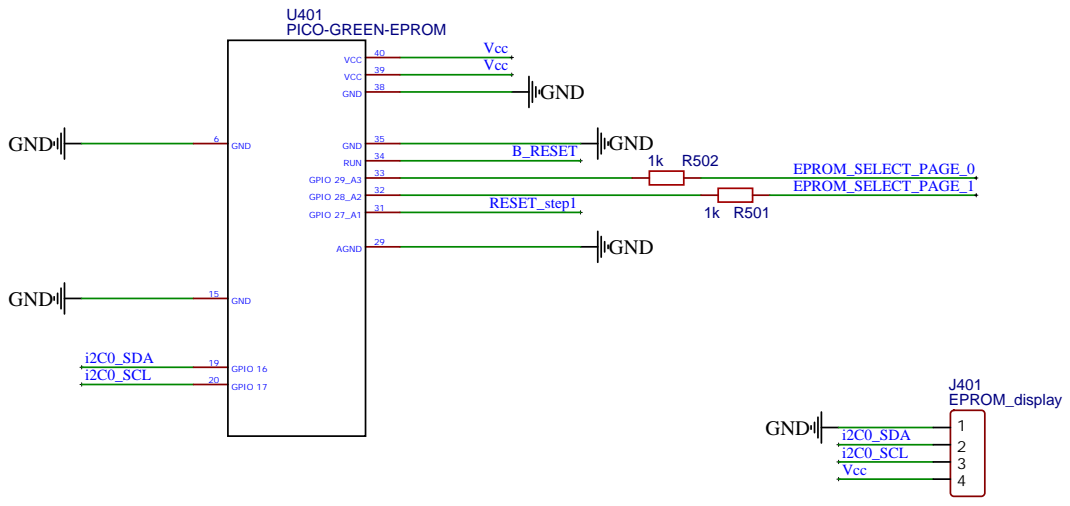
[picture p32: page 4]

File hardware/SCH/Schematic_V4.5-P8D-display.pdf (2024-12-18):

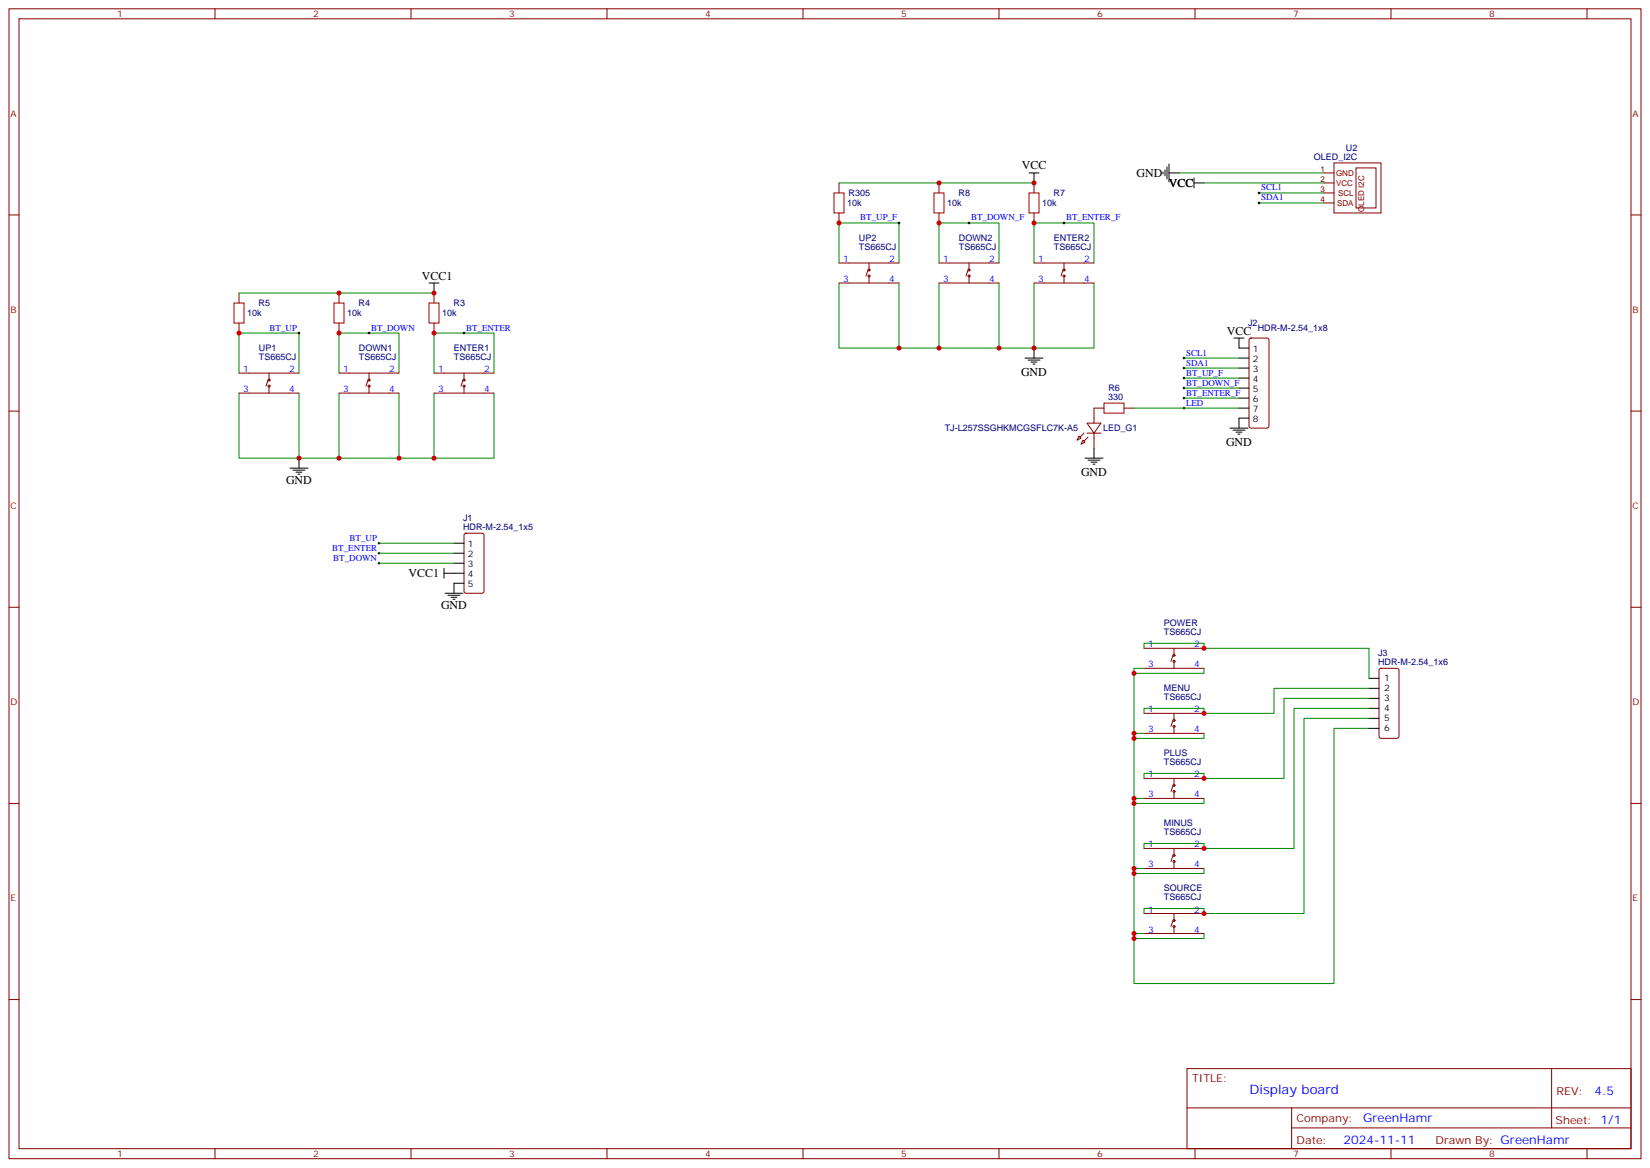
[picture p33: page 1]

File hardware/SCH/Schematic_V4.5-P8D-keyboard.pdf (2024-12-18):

# S1 10 S0 11 Y3 12 Y0 13 Y1 14 Y2 15 VCC 16

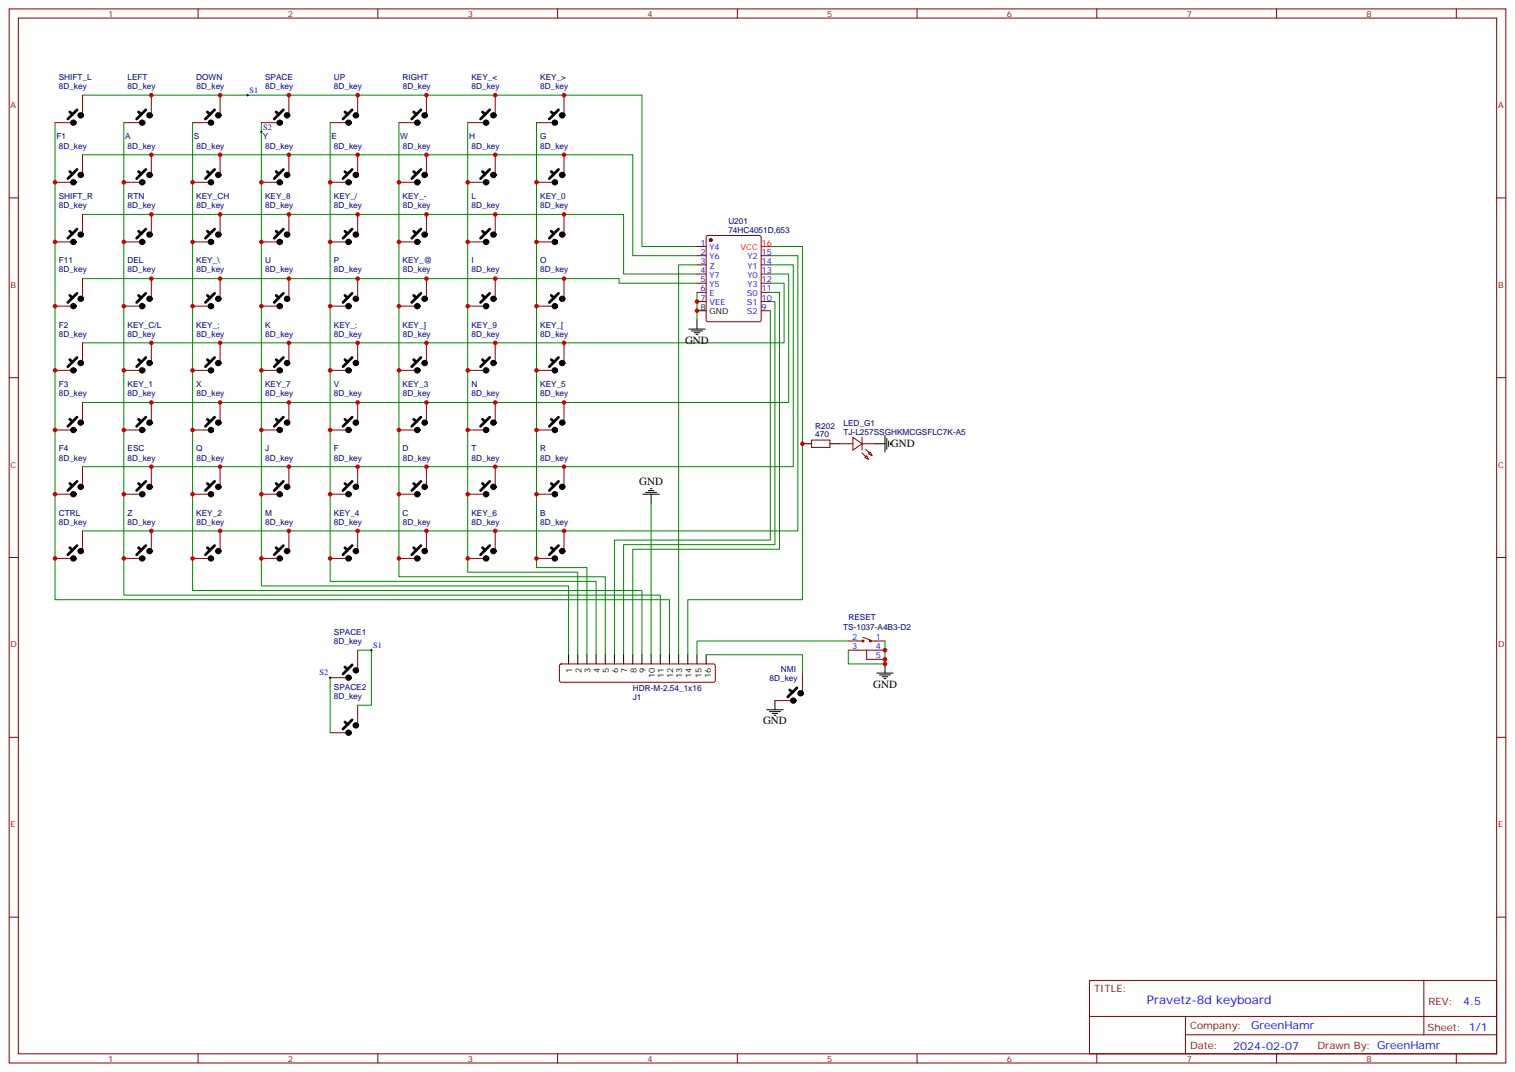
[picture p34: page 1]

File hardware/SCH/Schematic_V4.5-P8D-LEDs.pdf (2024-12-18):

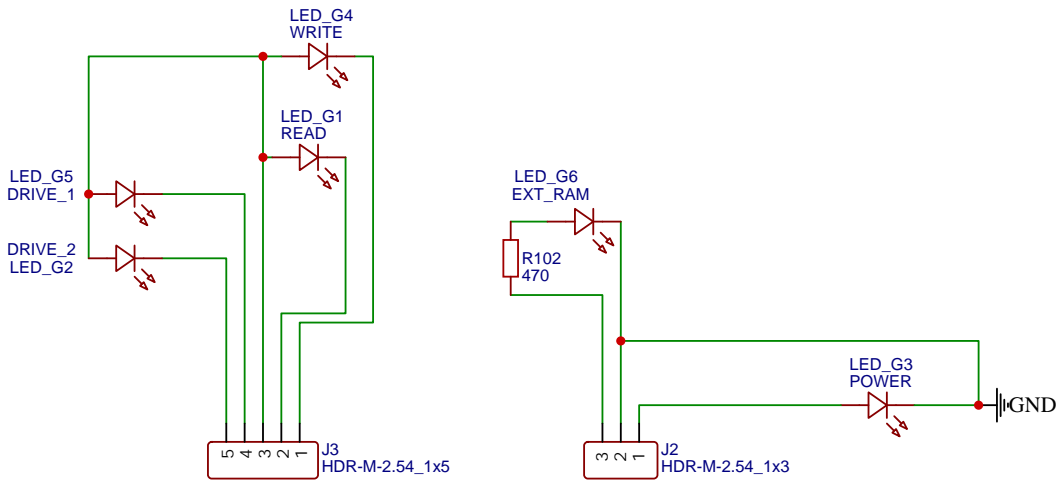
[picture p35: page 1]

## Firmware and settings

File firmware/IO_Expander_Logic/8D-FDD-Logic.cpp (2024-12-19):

#define VERSION_BASE 0
#define VERSION_MINOR 0
#define VERSION_BUILD 1


#include <stdio.h>
#include "pico/stdlib.h"
#include <stdlib.h>
#include <pico/time.h>
#include <math.h>
#include "pico.h"
#include <time.h>
#include "hardware/watchdog.h"
#include "pico/multicore.h"
#include "hardware/pio.h"
#include "hardware/clocks.h"
#include "extra16kRAM.pio.h"
#include "HardwareDefines.hpp"
#include "pio_init.hpp"
#include "eprom_floppy_content.hpp"


bool Trig_MAP;
bool Trig_EPROM;

bool PORT_io = false;
bool PORT_rw = false;
bool PORT_a4 = false;
bool PORT_a7 = false;
bool PORT_a0 = false;
bool PORT_a1 = false;
bool PORT_a14 = false;
bool PORT_a15 = false;


void core1_procedure() {
    uint p = 1;
    while (1) {
#ifdef WDT_ENABLE             
        watchdog_update();
#endif
        uint16_t dd = pio_sm_get_blocking(pio0, 0);
        PORT_io = dd & 0b000100000000;
        PORT_rw = dd & 0b001000000000;
        PORT_a4 = dd & 0b000000010000;
        PORT_a7 = dd & 0b000010000000;
        PORT_a0 = dd & 0b000000000001;
        PORT_a1 = dd & 0b000000000010;
        if (!PORT_io && !PORT_rw && !PORT_a4 && PORT_a7) {
            Trig_MAP = PORT_a0;
            Trig_EPROM = PORT_a1;
            pio_sm_exec(pio1, 0, pio_encode_set(pio_x, Trig_MAP));
        }
        if (!PORT_io && !PORT_rw && PORT_a4 && PORT_a7) {
            gpio_put(EPROM_PAGE_SELECT_0,PORT_a0);    
            gpio_put(EPROM_PAGE_SELECT_1,PORT_a1);    
        }
        gpio_put(PRAV8D_MAP_TRIG_LED,Trig_MAP);
        gpio_put(PRAV8D_EPROM_TRIG_LED,Trig_EPROM);



        uint8_t floppy_eprom_address = pio_sm_get_blocking(pio1, 1);
        pio_sm_put(pio1,1,FLOPPY_ROM_MEMORY[floppy_eprom_address | (Trig_EPROM << 9)]);

    }
}



//======================================================================================
//===    main program
//======================================================================================
int main() {
    Trig_MAP = false;
    Trig_EPROM = false;

    SetupHardware();
    initPio();
    multicore_launch_core1(core1_procedure);
    P8D_Reset();

#ifdef WDT_ENABLE     
    if (watchdog_caused_reboot()) {
    }
    watchdog_enable(WD_TIME, 1);
#endif    

    while (1) {
        // do something else

    }


}

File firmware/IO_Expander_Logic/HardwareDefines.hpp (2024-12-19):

#ifndef HARDWARE_DEFINES_H_
#define HARDWARE_DEFINES_H_

#include "hardware/vreg.h"


#define CPU_SPEED 1

#if CPU_SPEED == 1 
    #define CPU_CLOCK_FREQ 200000
    #define CPU_VOLTAGE VREG_VOLTAGE_1_00
#elif CPU_SPEED == 2
    #define CPU_CLOCK_FREQ  250000
    #define CPU_VOLTAGE VREG_VOLTAGE_1_10
#elif CPU_SPEED == 3
    #define CPU_CLOCK_FREQ 290400
    #define CPU_VOLTAGE VREG_VOLTAGE_1_20
#elif CPU_SPEED == 4
    #define CPU_CLOCK_FREQ 350000
    #define CPU_VOLTAGE VREG_VOLTAGE_1_25
#endif

#define PRAV8D_MAP_TRIG_LED 25
#define PRAV8D_EPROM_TRIG_LED 29

#define EPROM_PAGE_SELECT_0 23
#define EPROM_PAGE_SELECT_1 24

//#define WDT_ENABLE 1
#define WD_TIME 100 // in milliseconds

#define PRAV8D_A0 0
#define PRAV8D_A1 1
#define PRAV8D_A2 2
#define PRAV8D_A3 3
#define PRAV8D_A4 4
#define PRAV8D_A5 5
#define PRAV8D_A6 6
#define PRAV8D_A7 7

#define PRAV8D_IO 8
#define PRAV8D_RW 9
#define PRAV8D_A14 10
#define PRAV8D_A15 11
#define PRAV8D_F2 12

#define PRAV8D_D0 13
#define PRAV8D_D1 14
#define PRAV8D_D2 15
#define PRAV8D_D3 16
#define PRAV8D_D4 17
#define PRAV8D_D5 18
#define PRAV8D_D6 19
#define PRAV8D_D7 20

#define PRAV8D_RESET 21
#define PRAV8D_MAP 22

#define D0_D7_OE 26
#define PRAV8D_IO_Contr 27
#define APPLE_S_DEV_SEL 28



void SetupHardware() {
#if CPU_SPEED > 0    
    // set cpu frequency and voltage
    vreg_set_voltage(CPU_VOLTAGE);
#endif
    stdio_init_all();
#if CPU_SPEED > 0    
    set_sys_clock_khz(CPU_CLOCK_FREQ,true);
#endif
    gpio_init(PRAV8D_MAP);
    gpio_set_dir(PRAV8D_MAP, GPIO_OUT);
    gpio_put(PRAV8D_MAP,1);

    gpio_init(PRAV8D_MAP_TRIG_LED);
    gpio_set_dir(PRAV8D_MAP_TRIG_LED, GPIO_OUT);
    gpio_put(PRAV8D_MAP_TRIG_LED,0);

    gpio_init(PRAV8D_EPROM_TRIG_LED);
    gpio_set_dir(PRAV8D_EPROM_TRIG_LED, GPIO_OUT);
    gpio_put(PRAV8D_EPROM_TRIG_LED,0);


    gpio_init(EPROM_PAGE_SELECT_0);
    gpio_set_dir(EPROM_PAGE_SELECT_0, GPIO_OUT);
    gpio_pull_up(EPROM_PAGE_SELECT_0);
    gpio_put(EPROM_PAGE_SELECT_0,0);

    gpio_init(EPROM_PAGE_SELECT_1);
    gpio_set_dir(EPROM_PAGE_SELECT_1, GPIO_OUT);
    gpio_pull_up(EPROM_PAGE_SELECT_1);
    gpio_put(EPROM_PAGE_SELECT_1,0);

    gpio_init(PRAV8D_IO_Contr);
    gpio_set_dir(PRAV8D_IO_Contr, GPIO_OUT);
    gpio_pull_up(PRAV8D_IO_Contr);

    gpio_init(PRAV8D_RESET);
    gpio_set_dir(PRAV8D_RESET, GPIO_OUT);
    gpio_put(PRAV8D_RESET,0);

    gpio_init(PRAV8D_F2);
    gpio_set_dir(PRAV8D_F2, GPIO_IN);
    //gpio_pull_up(PRAV8D_F2);
    gpio_init(PRAV8D_RW);
    gpio_set_dir(PRAV8D_RW, GPIO_IN);
    //gpio_pull_up(PRAV8D_RW);
    gpio_init(PRAV8D_IO);
    gpio_set_dir(PRAV8D_IO, GPIO_IN);
    //gpio_pull_up(PRAV8D_IO);
    gpio_init(PRAV8D_A14);
    gpio_set_dir(PRAV8D_A14, GPIO_IN);
    //gpio_pull_up(PRAV8D_A14);
    gpio_init(PRAV8D_A15);
    gpio_set_dir(PRAV8D_A15, GPIO_IN);
    //gpio_pull_up(PRAV8D_A15);

    gpio_init(PRAV8D_A0);
    gpio_set_dir(PRAV8D_A0, GPIO_IN);
    //gpio_pull_up(PRAV8D_A0);
    gpio_init(PRAV8D_A1);
    gpio_set_dir(PRAV8D_A1, GPIO_IN);
    //gpio_pull_up(PRAV8D_A1);
    gpio_init(PRAV8D_A2);
    gpio_set_dir(PRAV8D_A2, GPIO_IN);
    //gpio_pull_up(PRAV8D_A2);
    gpio_init(PRAV8D_A3);
    gpio_set_dir(PRAV8D_A3, GPIO_IN);
    //gpio_pull_up(PRAV8D_A3);
    gpio_init(PRAV8D_A4);
    gpio_set_dir(PRAV8D_A4, GPIO_IN);
    //gpio_pull_up(PRAV8D_A4);
    gpio_init(PRAV8D_A5);
    gpio_set_dir(PRAV8D_A5, GPIO_IN);
    //gpio_pull_up(PRAV8D_A5);
    gpio_init(PRAV8D_A6);
    gpio_set_dir(PRAV8D_A6, GPIO_IN);
    //gpio_pull_up(PRAV8D_A6);
    gpio_init(PRAV8D_A7);
    gpio_set_dir(PRAV8D_A7, GPIO_IN);
    //gpio_pull_up(PRAV8D_A7);


    gpio_init(PRAV8D_D0);
    gpio_set_dir(PRAV8D_D0, GPIO_OUT);
    gpio_pull_up(PRAV8D_D0);

    gpio_init(PRAV8D_D1);
    gpio_set_dir(PRAV8D_D1, GPIO_OUT);
    gpio_pull_up(PRAV8D_D1);

    gpio_init(PRAV8D_D2);
    gpio_set_dir(PRAV8D_D2, GPIO_OUT);
    gpio_pull_up(PRAV8D_D2);

    gpio_init(PRAV8D_D3);
    gpio_set_dir(PRAV8D_D3, GPIO_OUT);
    gpio_pull_up(PRAV8D_D3);

    gpio_init(PRAV8D_D4);
    gpio_set_dir(PRAV8D_D4, GPIO_OUT);
    gpio_pull_up(PRAV8D_D4);

    gpio_init(PRAV8D_D5);
    gpio_set_dir(PRAV8D_D5, GPIO_OUT);
    gpio_pull_up(PRAV8D_D5);

    gpio_init(PRAV8D_D6);
    gpio_set_dir(PRAV8D_D6, GPIO_OUT);
    gpio_pull_up(PRAV8D_D6);

    gpio_init(PRAV8D_D7);
    gpio_set_dir(PRAV8D_D7, GPIO_OUT);
    gpio_pull_up(PRAV8D_D7);

}

void P8D_Reset() {
    gpio_put(PRAV8D_RESET,0);
    sleep_ms(10);
    gpio_put(PRAV8D_RESET,1);

}

#endif

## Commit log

2024-12-18 V4.5 Schematics and PCB gerbers
2024-12-19 Case design
    [PRAVETZ-8D - base.stl, PRAVETZ-8D - display_back.stl, PRAVETZ-8D - display_front.stl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]
2024-12-23 STL fix
    [PRAVETZ-8D - hinge_left.stl, PRAVETZ-8D - hinge_right.stl, PRAVETZ-8D - top.stl]
